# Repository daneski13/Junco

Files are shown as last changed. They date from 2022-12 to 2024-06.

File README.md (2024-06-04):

<h1 align="center">Junco</h1>






Named after a small North American bird, Junco is a 60% Raspberry Pi Pico powered split keyboard boasting a 4x6 layout with an aggressive columnar stagger, 2-4 rotary encoders, and per-key RGB lighting.

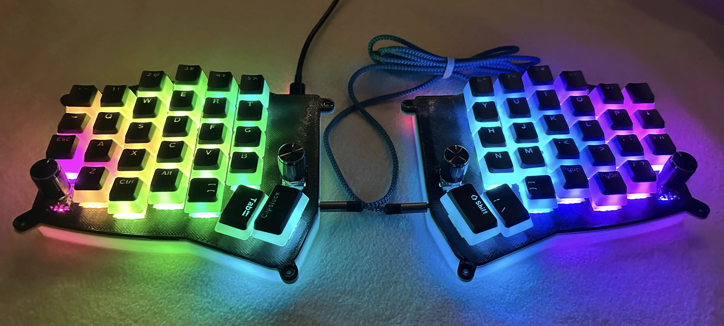
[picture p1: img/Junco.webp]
Junco


Want to contribute? Check out [Contributing](./CONTRIBUTING.md).

Junco is inspired by the excellent [crkbd](https://github.com/foostan/crkbd), [Iris](https://keeb.io/collections/iris-split-ergonomic-keyboard/products/iris-keyboard-split-ergonomic-keyboard), [Kimiko](https://github.com/Keycapsss/Kimiko), [Sofle](https://github.com/josefadamcik/SofleKeyboard), and [Ferris](https://github.com/pierrechevalier83/ferris) keyboards. Massive thanks to [@JellyTitan](https://github.com/JellyTitan) for the wiring overhaul.

- [Design Philosophy and Quirks](#design-philosophy-and-quirks)
  - [Philosophy](#philosophy)
  - [Quirks](#quirks)
- [Build Guide / Assembly](#build-guide--assembly)
  - [Parts](#parts)
    - [Required](#required)
    - [Optional - RGB](#optional---rgb)
  - [Soldering](#soldering)
    - [Diodes](#diodes)
    - [RGB (Optional)](#rgb-optional)
    - [Pico](#pico)
    - [Hot-swap Sockets](#hot-swap-sockets)
    - [TRRS jack and Rotary Encoders](#trrs-jack-and-rotary-encoders)
  - [Case](#case)
  - [Flashing the firmware](#flashing-the-firmware)
- [Troubleshooting](#troubleshooting)
  - [No LEDs are working](#no-leds-are-working)
  - [Some LEDs are not working](#some-leds-are-not-working)
  - [An entire row or column of keys is not working](#an-entire-row-or-column-of-keys-is-not-working)
  - [Random key or keys not working](#random-key-or-keys-not-working)

## Design Philosophy and Quirks

### Philosophy

In my search for an ergonomic split keyboard, I came across several great keyboards, but I craved a combination of features and ideas from several with my own flavor. Iris' aesthetics, Kimiko's stagger and layout, elements of Ferris' philosophy.

I also wanted to use Raspberry Pi Picos for the controller as it has many advantages over the ProMicro that is normally used in custom keyboards. At the time, Pico powered keyboards were not yet really a thing and weren't yet supported by the main QMK branch. Thus, I created my own keyboard.

The Junco was designed around a set of goals, similar in vain to the Ferris.

**Goals:**

- Low-Cost
- Raspberry Pi Pico / RP2040
  - Superior flash storage and processing power compared to the common ATMega32 ProMicro
  - Faster than STM32 blackpill with more flash storage at the same cost or less
- Comfort
  - Aggressive Columnar Stagger
- Aesthetics
  - Almost all soldering done on the backside of PCB, optional RGB
- 60% layout
  - Near perfect blend of compactness and easy use without crazy combos or layer gymnastics
- Multiple rotary encoder support
- Hot-swap switches
- Plug and play either side of the split
  - Convenience and traveling
  - Flexible cable management
- Minimal different parts and easy to source
  - No need to buy a different types of LEDs or diodes. No reset switches, capacitors, resistors etc. required.

**Non-goals:**

- Reversible PCB
  - Can make assembly confusing and more error prone
- Multi-switch support
  - MX switches should use MX spacing, Choc switches should use Choc spacing.
- OLED Support
  - OLEDs are an added cost and somewhat comprise the aesthetics in my opinion. Don't find useful for a keyboard, more of a novelty.

### Quirks

Being my first venture into keyboard design... Junco unfortunately suffers from a few "quirks" at the moment that may or may not bother you:

- The case files currently provided in this repo assume PCB mounted switches and uses a 3mm switch plate that is flush with the PCB. This presents some problems that a more proper suspended switch plate would not have:
  - Mounting the Pico on the backside with headers causes a bit of the header to be exposed on the front side of the PCB, so the switch plate provided in this repo will not sit flush with the PCB.
  - The TRRS jack is also soldered on the backside, causing another uneven surface for the switch plate.
  - Thus, material must be removed from the back of the switch plate in the proper places for a flush fit.
    - Heat-gunning the switch plate in the proper area, lining it up with the PCB, and squishing provides a quick and *dirty* solution if done correctly.
  - **PRs are welcome to improve upon the case files or to create new cases as I am a 3D design novice.** A proper fix would be to have the PCB rest on the middle section's lip about 1.5mm below the switch plate. This would also allow plate mounted switches to properly latch onto the switch plate.

## Build Guide / Assembly

### Parts

#### Required

Where "56-58" is the count, 58 is needed with 2 rotary encoders. subtract from 58 every additional encoder (4 encoders 56, with 3 encoders 57).

| Name | Count | Remarks | Potential Storefront |
| --- | --- | --- | --- |
| PCB | 2 (1 left and 1 right)  | PCBs can be ordered from manufacturers such as JLCPCB and LCSC | |
| MX Hot-swap Sockets | 56-58 | | |
| Diodes | 62 | Surface mount SOD-123 1N4148, _or_ through-hole 1N4148 diode. These are both common and inexpensive, any one should do. Through hole is usually easier to solder. | SMD: [AliExpress](https://www.aliexpress.us/item/2251832663565152.html) <br>[JLCPCB Part#: C2972760](https://jlcpcb.com/partdetail/3368026-1N4148SOD123/C2972760)<br> Through-hole: [AliExpress](https://www.aliexpress.us/item/2251832473773777.html) |
| Raspberry Pi Picos | 2 | PCB is specifically designed with the official Pico and YD-2040 type clone in mind, however several [other clone types](https://docs.google.com/spreadsheets/d/1LPjy6F5lHfUkmsrM5zlZmc5auYy5YBakW8Awe6hYFWo) should be compatible (Waveshare, WeAct, EstarDyn, Tenstar). Also, the case is currently designed assuming the Pico is soldered with [headers](https://www.sparkfun.com/products/17907), but surface mounting the Pico is supported on the PCB. | [AliExpress, YD-2040](https://www.aliexpress.us/item/3256803909832318.html) |
| TRRS Jacks | 2 | PJ-320A | [AliExpress](https://www.aliexpress.us/item/2255800474897706.html) |
| TRRS Cable (3.5mm "Headphone" Cable) | 1 | TRRS (4 pole) is currently required, not TRS (3 pole) | |
| MX Style Switches | 56-58 | | |
| Key Caps | 56-58 | | |
| Rotary Encoders and Caps | 2-4 | EC-11 Rotary Encoder | [AliExpress](https://www.aliexpress.us/item/2261799870168498.html) |
| M3 6mm or 6mm+ Screws and Nuts | 8 | | |
| Case | 1 Left Set, 1 Right Set | Case files are located in the [case folder](./Case). | |
| Micro USB Cable or USB-C Cable | 1 | USB cable for connecting the keyboard to your computer, dependent on what the Pico you chose uses. | |

#### Optional - RGB

These parts are necessary for the RGB lighting.

| Name | Count | Remarks | Potential Storefront |
| --- | ----- | --- | --- |
| 74AHCT1G125 Voltage Level Shifter/ Bus Buffer | 2 | SOT23-5 Footprint <br/> <br/> Required for LEDs to work properly, Pico runs at 3.3V while the LEDs will require 5V | [AliExpress](https://www.aliexpress.us/item/3256803831434811.html) <br> [JLCPCB Part# C7484](https://jlcpcb.com/partdetail/TexasInstruments-SN74AHCT1G125DBVR/C7484) |
| RGB SMD LEDs (Prefer SK6803MINI-E) | 74 | The 3MA SK6803MINI-E is highly recommended over the more traditional 12MA SK6812MINI-E due to its smaller current draw, allowing the LEDs to be very bright at manageable wattage. | [AliExpress](https://www.aliexpress.us/item/3256803450292556.html) <br> [JLCPCB Part# C5184589](https://jlcpcb.com/partdetail/Normand-SK6803MINIE/C5184589) |

### Soldering

The PCB is not reversible, there is a dedicated right and left half in the KiCad PCB files. Almost all of the soldering will occur on the backside of the PCB. 

#### Diodes

Solder the diodes as you see in the photo.
SMD diodes are soldered on the back of the board. 
Through-hole diodes are inserted on the back of the board, and soldered on the front.

> [!WARNING]
> **Note** that the diodes have polarity, ensure the line on the diode matches the silkscreen.

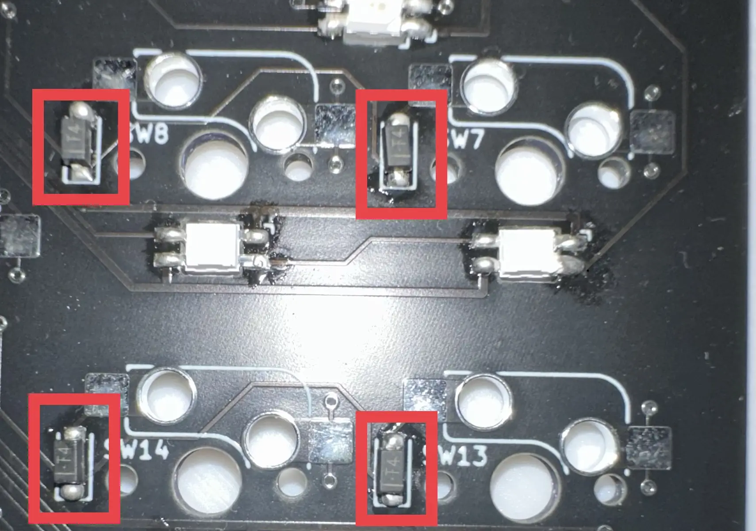
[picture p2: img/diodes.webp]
Soldered Diodes

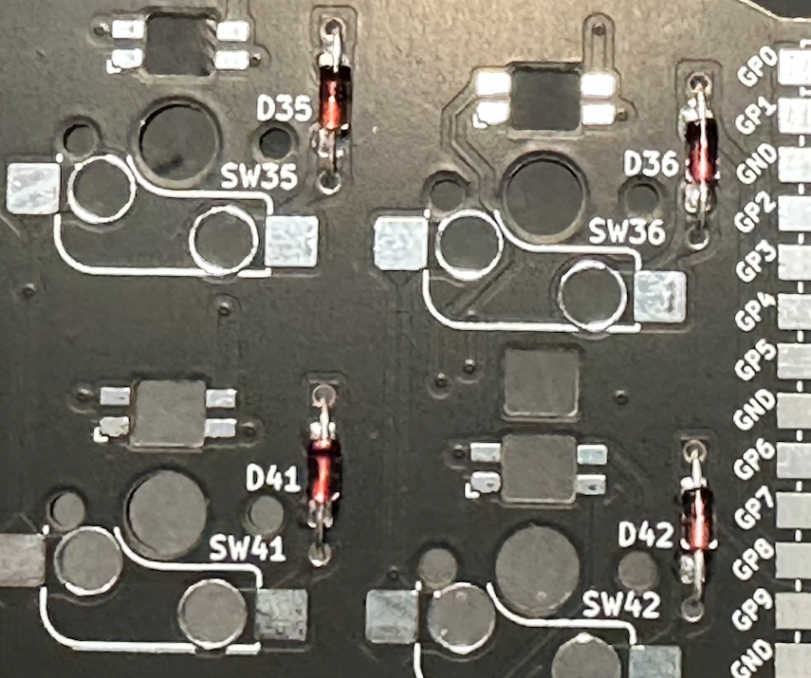
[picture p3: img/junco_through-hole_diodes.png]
Soldered Diodes

#### RGB (Optional)

All LEDs must be soldered to the PCB for RGB to work properly, even if you will not be using backlight or will be using an encoder that covers an LED. (They are wired in serial).

First solder the level shifter. It's tiny & squirrley - [drag soldering](https://www.youtube.com/watch?v=wUyetZ5RtPs)" is a good method. See photo:

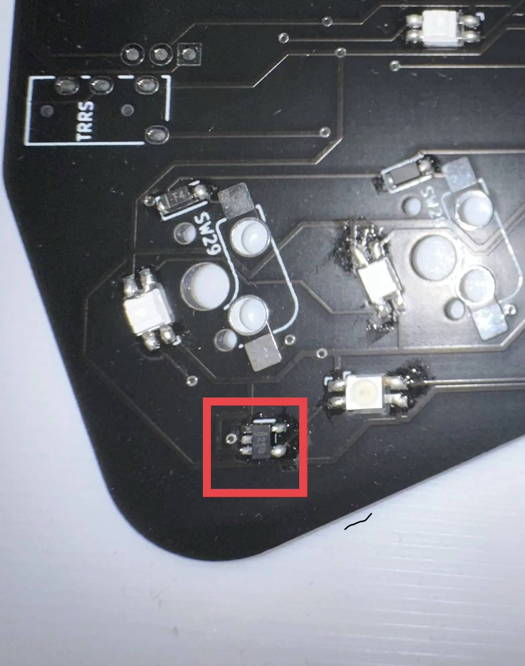
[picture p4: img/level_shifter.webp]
Level Shifter Soldered


All LEDs will be soldered facing _down into the board_. The LEDS for per-key RGB will be soldered on the back of the board, while the LED's for the underglow will be soldered on the front of the board.

> [!WARNING]
> **Note** the LED orientation is very important. One of the pads on each LED (the ground pin) will be misshapen relative to the others, this pad should connect to the PCB pad that is marked by the L shape on the silkscreen. For a sanity check, a corner of the LED's front-side will also be "cut", this corner must also line up with the L shape on the silkscreen.

 Blue is LEDs that will be installed on the underside of the board, facing the front-side of the PCB for the per-key lighting. Red will be installed on the front of the board for the underglow:

LED Orientation

Per Key leds soldered on the backside, while underglow LEDs ssoldered on the opposite side:
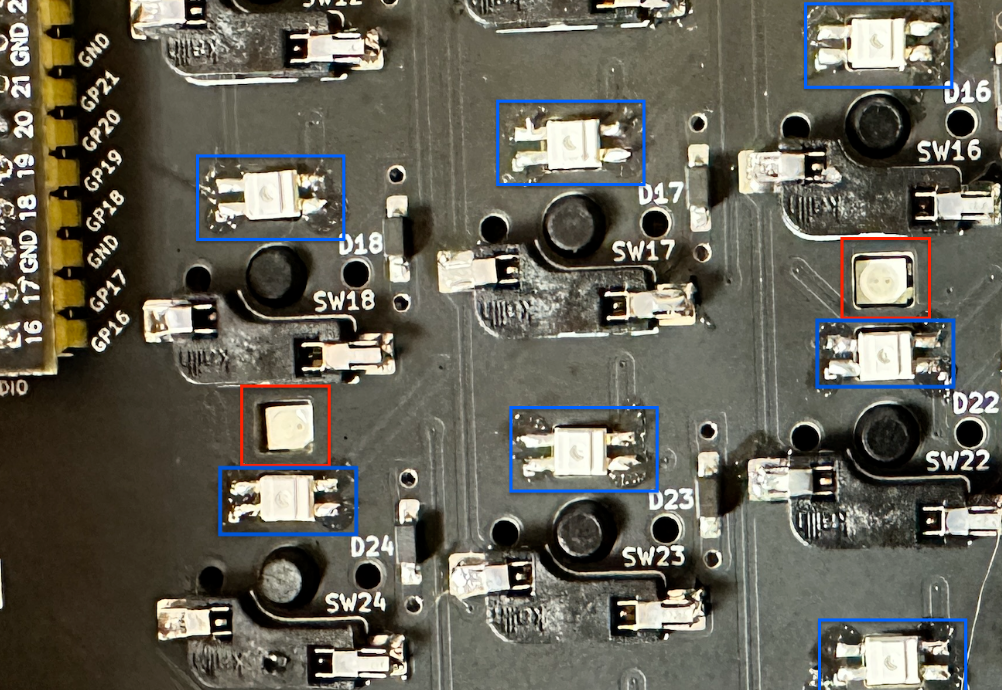
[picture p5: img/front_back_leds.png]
LEDs Soldered


Ground pin orientation:

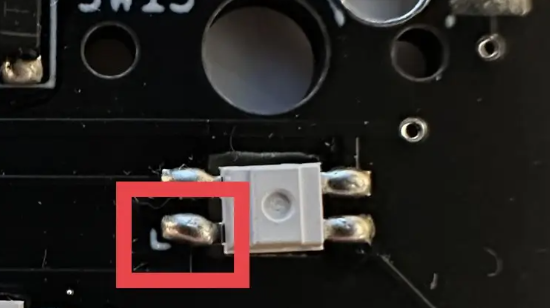
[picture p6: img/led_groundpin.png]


After you finish the next step of soldering the Pico to the PCB, recommend plugging the keyboard in and flashing QMK to ensure the LEDs are lighting up. If there are any issues, check the troubleshooting section.

#### Pico

If you are soldering the Pico surface mount style, go ahead with soldering it to the backside of the PCB and you can skip to the next section.

If you are soldering the Pico using headers, first solder the Pico to the headers and then the header/Pico to the PCB. 

**Ensure that you are soldering the Pico/Header onto the backside of the PCB.**

The best way to go about this method is to rest the shorter end of the headers in the through-holes of the PCB on a flat surface and place the Pico on top, through the longer end of the header. This will stabilize the headers somewhat and ensure proper spacing. Solder the Pico to the 2 header pins on the both the "top" and "bottom" of the Pico to hold it in place. Proceed to solder the Pico to the rest of the header's pins.

After the Pico is soldered to the header, flip the PCB over and solder the sticking-out header pins to the PCB. Start with the 2 "top" and 2 "bottom" header pins to hold it in place, being sure to minimize the space between the header's plastic and the PCB. Proceed to solder the PCB to the rest of the header's pins.

The end result will look like this:

Backside of PCB:

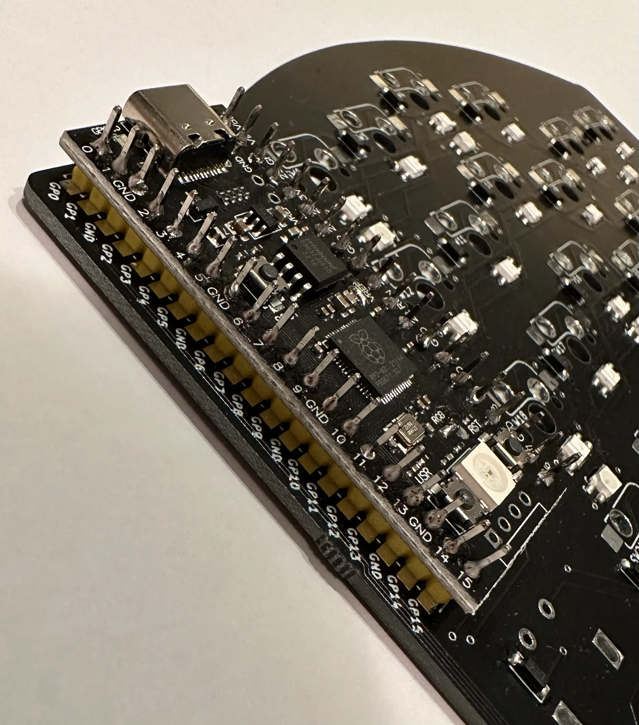
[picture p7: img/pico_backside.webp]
Pico Soldered, PCB Backside


Front-side of PCB:

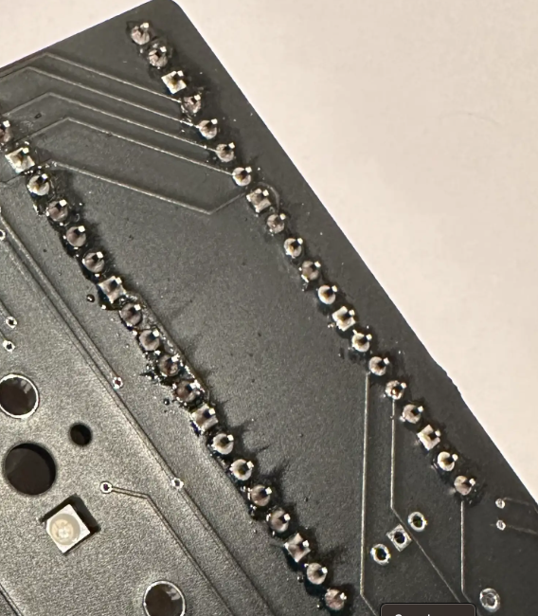
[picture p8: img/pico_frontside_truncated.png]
Pico Soldered, PCB Frontside


#### Hot-swap Sockets

Place hot-swap sockets on the backside of the PCB and solder. See photo:

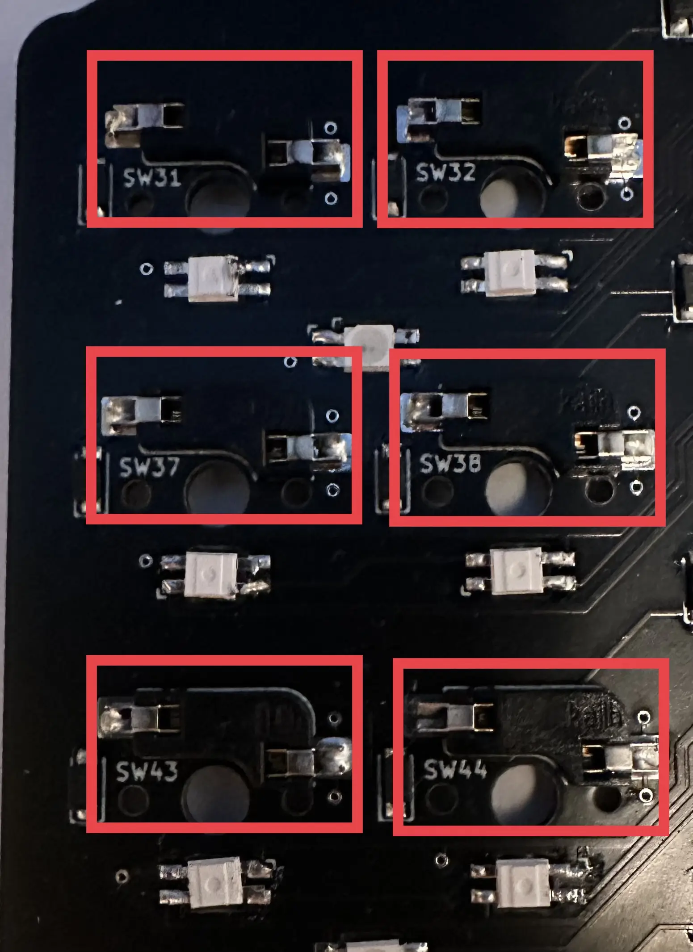
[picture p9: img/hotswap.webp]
Hot-swap Sockets Soldered


#### TRRS jack and Rotary Encoders

The process for soldering the TRRS jack and the process for the rotary encoders are very similar.

On the **backside** of the PCB, place the TRRS jack. On the front-side of the PCB, bend the pins of the TRRS jack to "latch" onto the PCB and solder.

Backside PCB:

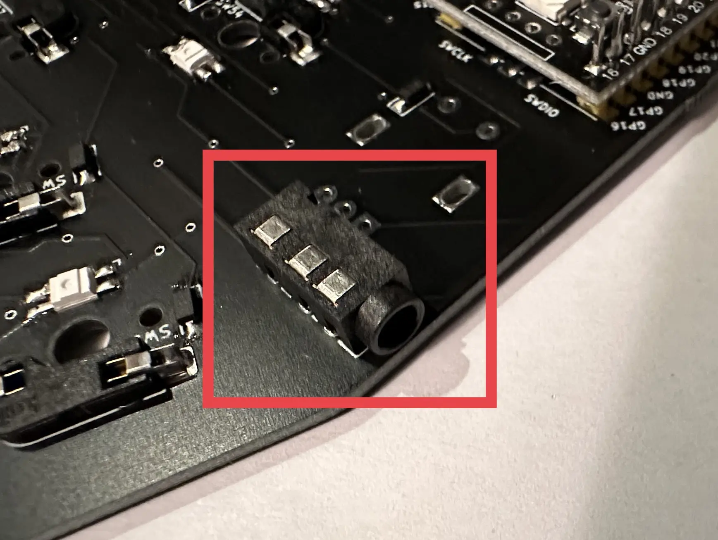
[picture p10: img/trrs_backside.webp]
TRRS Soldered, Backside


Front-side PCB:

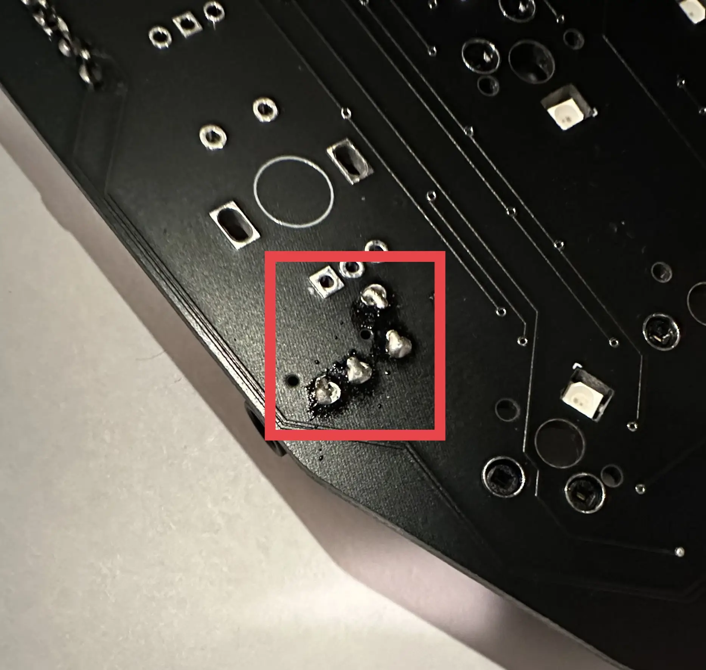
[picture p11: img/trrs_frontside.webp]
TRRS Soldered, Front-side


On the **front-side** of the PCB, place the rotary encoder(s). On the backside of the PCB, bend the pins of the encoder to "latch" onto the PCB and solder.

Front-side PCB:

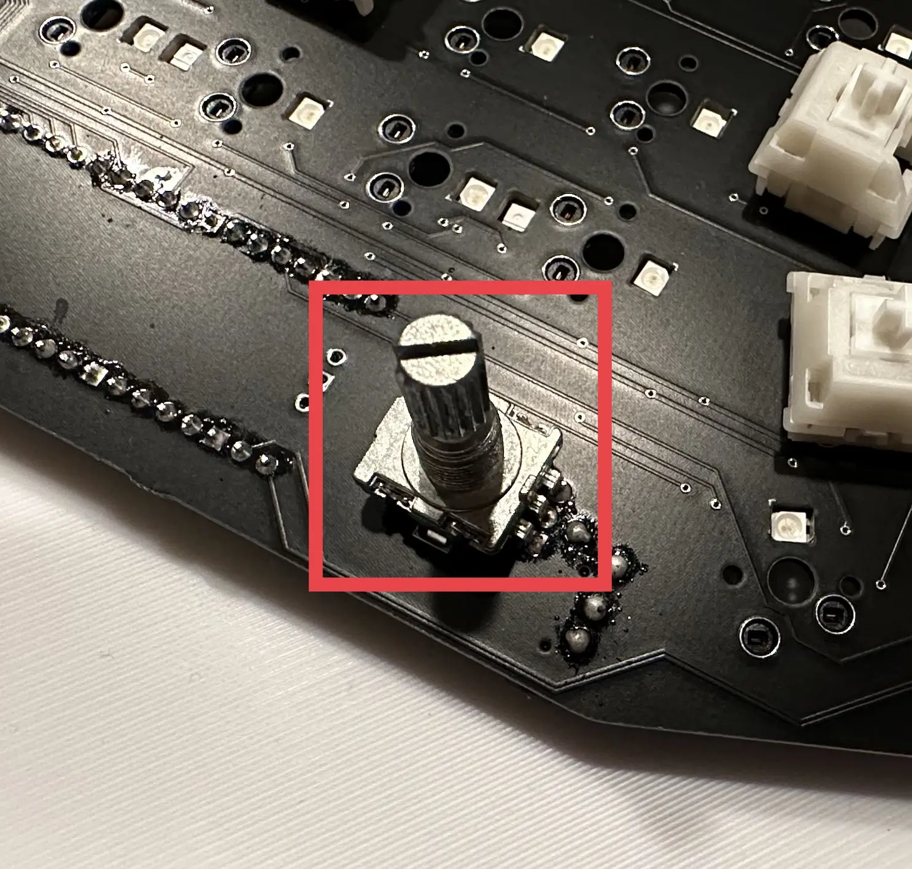
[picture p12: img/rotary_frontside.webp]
Rotary Encoder Soldered, Front-side


Backside PCB:

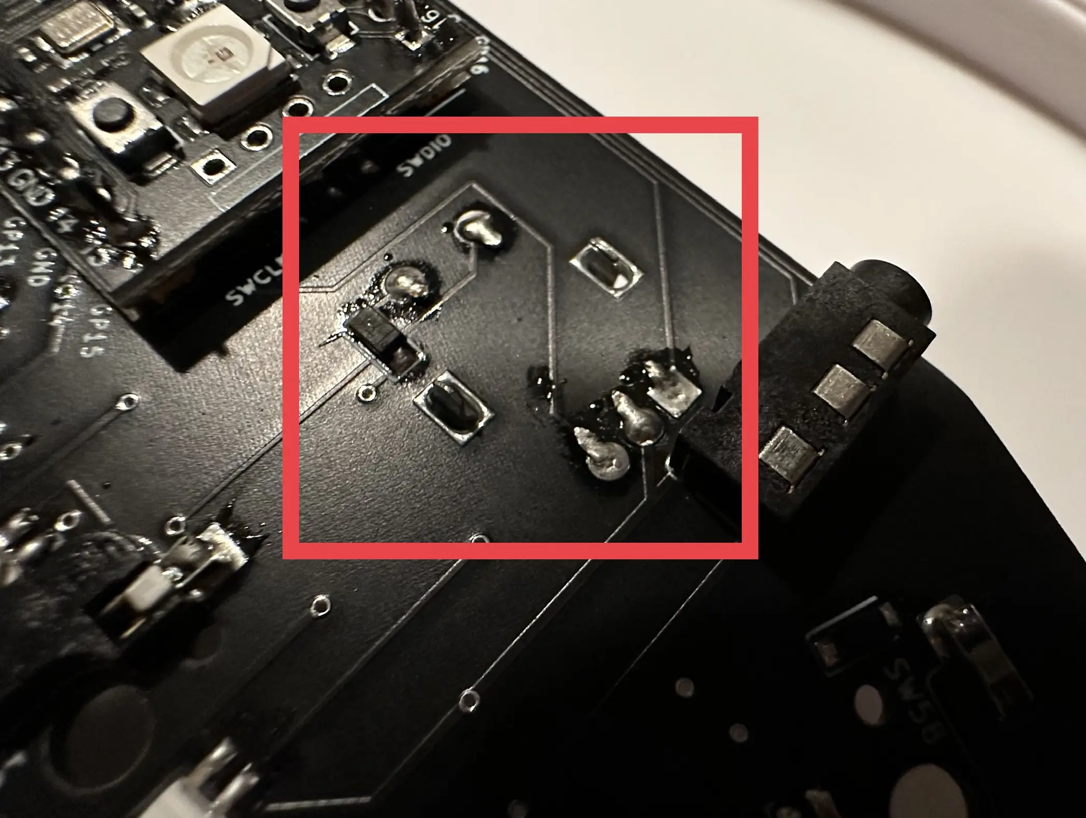
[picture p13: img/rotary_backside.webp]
Rotary Encoder Soldered, Back-side


### Case

At the moment, the case files included in the [case directory](./Case) support 3D printing of a case assuming PCB mounted switches (since the 3mm switch plate is resting on the PCB). Since I do not own or have easy access to a 3D printer, the case was designed to be easy to print with 3rd party printing services in-mind such as Treatstock.

Raw files are provided for designing your own case if you see fit. Further work on the case may occur in the future to properly suspend the switch plate. PRs are welcome.

The case is comprised of 4 parts, 8 M3 screws, and 8 M3 nuts.

To have a functional case you need the Bottom Left and Bottom Right along with a Left Switch Plate and a Right Switch Plate. 4 M3 screws and their nuts will hold the switch plate and bottom together for each side of the split. Recommend printing the bottom in white at 40% infill so the underglow LEDs can bleed through.

The naming schemes "- 2 Rotary" and "- 4 Rotary" are products of the raw files used to model the case.

The switch plates named "- 2 Rotary" assume 1 rotary encoder will be used on that side of the split. One by they thumb keys.

The switch plates named "- 4 Rotary" assume 2 rotary encoders will be used on that side of the split. One by the thumb keys and one in the far bottom corner

If you would like to have 3 rotary encoders rather than 2 total or 4 total you would use both variants. The side that will have 2 rotary encoders will use the "- 4 Rotary", while the other side with 1 rotary encoder will use the "- 2 Rotary".

As mentioned in [design quirks](#quirks), there are some problems with making the switch plate flush with the PCB. After you get it flush, you can completely assemble your keyboard! Assembly goes in the reverse of the following:

-- Keycaps --

-- Switches --

-- Case Switch Plate -- (screw + nut connect the plate with the bottom)

-- PCB --

-- Case Bottom --

### Flashing the firmware

Junco is powered by the QMK firmware, see the [build environment setup](https://docs.qmk.fm/#/getting_started_build_tools). Brand new to QMK? Start with the [Complete Newbs Guide](https://docs.qmk.fm/#/newbs).

For users wanting something a little more fun, check out my keymap folder [here](./qmk) and my keymap [here](./qmk/keymaps/deluxe).

Flashing instructions can be found [here](https://github.com/qmk/qmk_firmware/tree/master/keyboards/junco).

Congratulations and enjoy your split keyboard!

## Troubleshooting

### No LEDs are working

Try the following until problem solved:

1. Ensure the level shifter is properly soldered onto the PCB, re-solder as needed.
2. There is a diode without a corresponding switch located to the top right of the Pico on both sides of the split, check and re-solder that diode as needed.
    1. Short the pads on either side of the diode on both halves.
       1. If some the LEDs turn on, re-solder the diodes. Replace it if problem persists.
       2. If no LEDs turn on after shorting the diode's pads, there is likely a problem with the first LED, move to the next section for the first LED in the electrical order. If that still doesn't work, the level shifter is likely damaged and needs to be replaced.

### Some LEDs are not working

Go through the LED electrical order (pictured below) until you reach the problem LED. That LED **or** the one previous to it has a problem.

LED Electrical Order (1-8 are underglow):

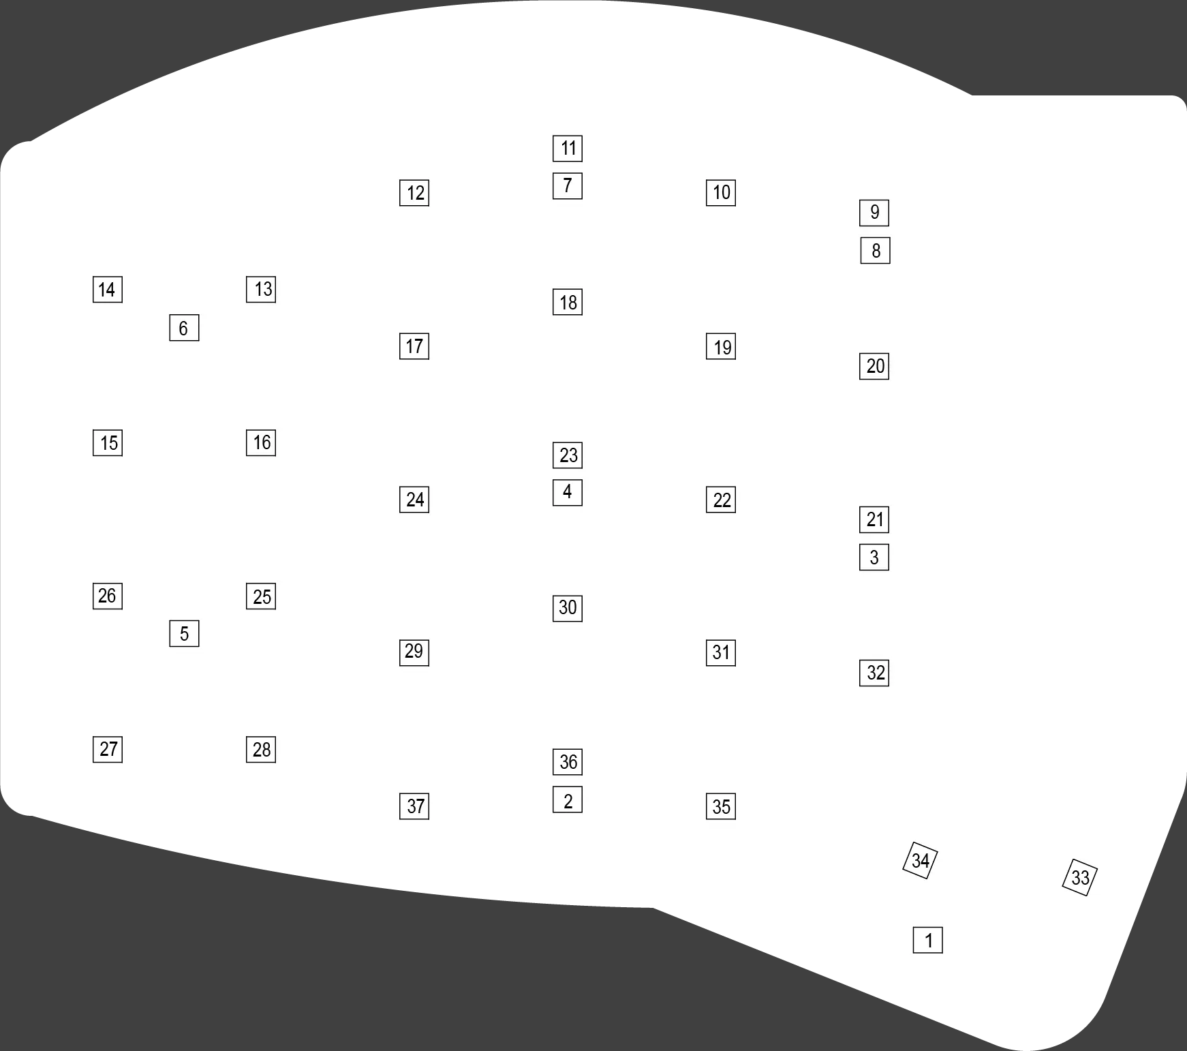
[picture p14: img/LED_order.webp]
LED Order


Right side is identical but mirrored.

Try the following until problem solved:

1. Check that the pads of LED not turning on and its previous are soldered correctly, re-solder for a better connection as needed.
2. Double check that the LED not turning on is in the correct orientation.
3. If the soldering looks good and the orientation is correct, try re-soldering all the pads any way for good measure.
4. If re-soldering didn't work than the LED is likely dead or damaged in which case replace it.

### An entire row or column of keys is not working

In this case, there is most likely a problem with the PCB's connection to the Pico. Note that the bottom row of keys is staggered by 2, so the the corresponding matrix column is shifted.

Rows:

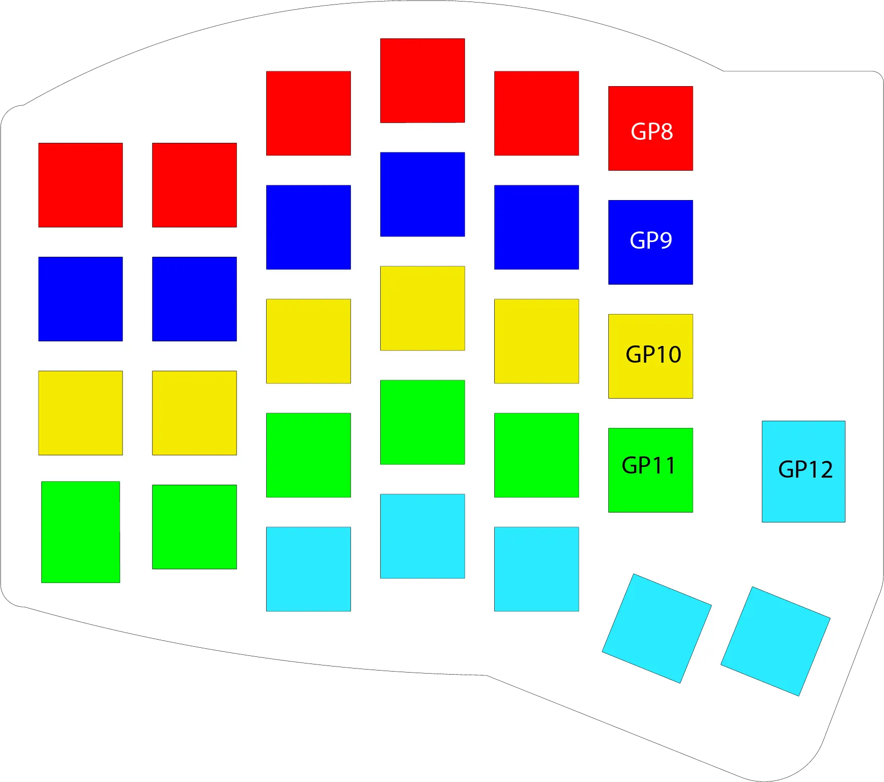
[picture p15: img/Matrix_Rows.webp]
Matrix Rows


Cols:

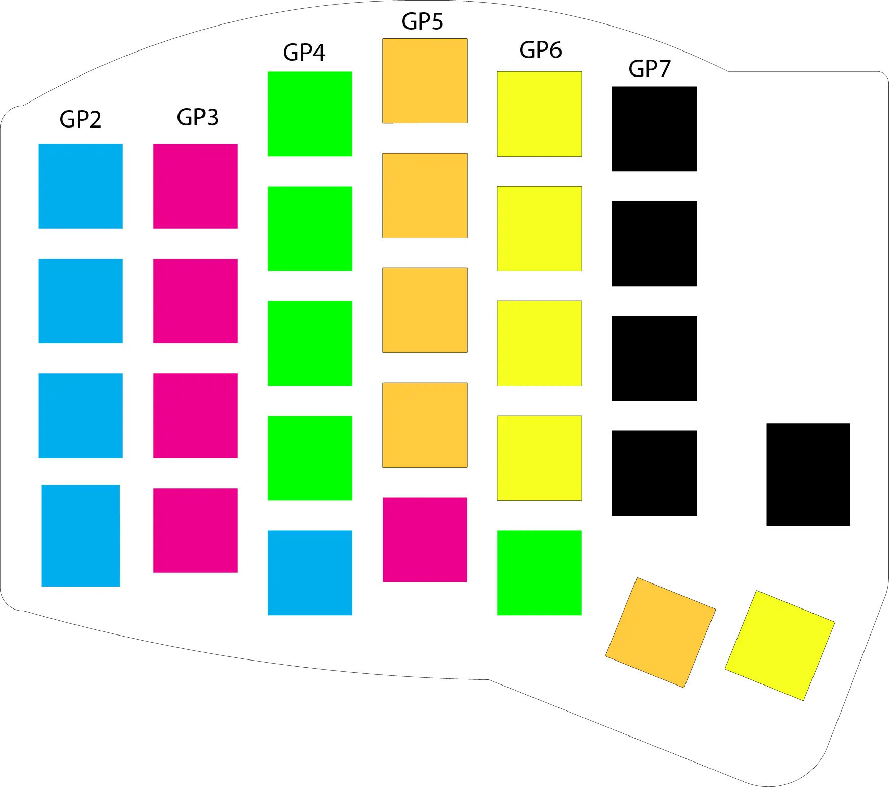
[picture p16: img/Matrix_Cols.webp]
Matrix Rows


The right side is identical but mirrored.

Try the following until problem solved:

1. Double check that you have soldered the Pico into the correct holes.
2. Ensure the soldering connections of the Pico to the PCB is good (if you used a header to solder the Pico onto the PCB one of the connections to the through-hole is likely bad). Re-solder as needed.
3. If none of the connections are obviously bad, use the image above to see what row/column corresponds to what connection (GP numbering on back of PCB). Re-solder that specific connection for good measure and test.
4. If re-soldering the connection didn't work, your Pico or PCB is likely damaged. Rule out the Pico by directly shorting the that row or column's corresponding pad on the Pico with another column/row pad (connecting one row and one column). If a key press is registered, there is a problem with your PCB, see the bottom of the next section about potentially fixing paths on the PCB. If no keypress is registered, the Pico is damaged and have fun de-soldering your Pico (hot-air station or careful work with a heat gun is the best way).

### Random key or keys not working

Note that the bottom row of keys is staggered by 2, so the the corresponding matrix column is shifted. See the photo in the above section.

If it's not a row or column of keys, than there is a bad connection between your switch and PCB.

Try the following until problem solved:

1. Re-seat the switch in the hot-swap socket.
2. Try a different switch.
3. Check the soldering of the hot-swap socket to the PCB, re-solder as needed
4. Short the PCB pads on either side of the hot-swap socket, if that registers a keypress, the hot-swap socket is bad and needs to replaced.
5. Check the diode.
   1. Check the soldering of the diode to the PCB and re-solder as needed.
   2. Double check that the diode is oriented correctly.
   3. Make sure diode actually works and has a good connection.
      1. Read the diode with a multimeter, typically reads a little more than 0.6. Higher numbers usually means the solder connection is bad, de-solder and re-solder the diode. If not reading, diode is bad and needs to be replaced.
      2. No multimeter? Short either side of the diode and press the key. If that works either the diode's connection is bad and re-solder, or the diode is dead and needs to be replaced.
6. If none of the above worked, the problem is most likely with the paths inside the PCB.
   1. You can try the following: (credit to [crkbd](https://github.com/foostan/crkbd) guide)
      1. "Visually inspect the PCB. If it looks scratched or damaged anywhere along the path from ProMicro to diode to keyswitch, the path might be interrupted. If you find a spot that looks damaged, you can use some wire to bypass the section that is damaged (e.g. connecting the ProMicro directly to the first pad of the diode). If this fixes the key, then you can either opt to keep the wire permanently, or you can try to repair the path. The path can be repaired by carefully scraping off the paint from a section of the path that is okay on either side of the damaged part (use a small flat head screwdriver intended for electronics). Then clean carefully with alcohol and solder a new connection. Youtube might have some guides on how to do this."

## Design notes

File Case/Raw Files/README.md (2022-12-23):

# Raw Files

The DXF files contained in this directory are in millimeters and generated from the KiCad PCB. They should be your starting point for creating a case.

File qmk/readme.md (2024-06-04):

> [!NOTE] 
> This folder contains most of the original QMK firmware files for the keyboard, some features were rejected by the main QMK repository as they were too user-keymap specific, complex, and depend on some internal workings of QMK that are subject to change/break in the future. This is not even currently guaranteed to work with the latest QMK firmware, but at the very least is an interesting starting point for anyone looking to make complex features for their own keyboards.
> 
> As such, they are not included in the main QMK repository. If you want to use these features, you will have to use this repo's junco keyboard files. Particularly of note is the [Junco Sync Feature](#junco-sync-) and [deluxe keymap](./keymaps/deluxe/)

# Junco <!-- omit from toc -->

Junco

Junco is a 60% Raspberry Pi Pico powered split keyboard boasting a 4x6 layout with an aggressive columnar stagger. It has 5 "thumb" keys on either side, support for 2-4 rotary encoders, and per-key RGB lighting.

- Keyboard Maintainer: [Dane Skalski](https://github.com/Daneski13)
- Hardware Supported: Junco PCB, Raspberry Pi Pico
- Hardware Availability: [PCB, Case, Parts List](https://github.com/Daneski13/Junco)

Remember you have to flash both halves of the keyboard for it to work!

Make example for this keyboard (after setting up your build environment):

    make junco:default

Flashing example for this keyboard:

```bash
# For flashing the left half...
make junco:default:uf2-split-left
# or the qmk cli equivalent:
qmk flash -kb junco --keymap default -bl uf2-split-left

# For flashing the right half...
make junco:default:uf2-split-right
# or the qmk cli equivalent:
qmk flash -kb junco --keymap default -bl uf2-split-right
```

See the [build environment setup](https://docs.qmk.fm/#/getting_started_build_tools) and the [make instructions](https://docs.qmk.fm/#/getting_started_make_guide) for more information. Brand new to QMK? Start with our [Complete Newbs Guide](https://docs.qmk.fm/#/newbs).

## Bootloader <!-- omit from toc -->

Enter the bootloader in 3 ways:

- **Bootmagic reset** (works after you have flashed once): Hold down the top far corner key while plugging in the keyboard (`~` left half, `-` right half). This will also clear the EEPROM.
- **Physical reset button**: Hold the `BOOT` button on the Pico and press the `RST` button on the Pico, release the the `RST` button before the `BOOT` button.
- **Keycode in layout**: In the default layout, the `Bootloader` keycode is above home row pinky on the right side's adjust layer.

Once you enter the bootloader, the keyboard will show up as a USB device on your computer, you could drag and drop a firmware file to flash it, but I recommend using the flash commands for the respective side.

## Junco Sync <!-- omit from toc -->

Junco has a special feature called Junco Sync that will automatically save and sync certain data between the halves of the split. This means that no matter which side you plug in, whenever you change your default layer in a keymap with `DF(layer)`, change your RGB settings with `RGB_***` keycodes, or use one of the `MAGIC_***` keycodes, the data will be saved to EEPROM and synced to the other half of the keyboard. If you choose to plug the other half into a computer, your settings will be the same.

Also, if you ever clear the EEPROM with `EE_CLR` or reboot with `QK_RBT` on one half, the other half will automatically do the same.

To enable Junco Sync in your firmware, uncomment `#define JUNCO_SYNC_ENABLE` in your `config.h` so it looks like this:

```c
/*  - Junco Sync -
    Enables a special feature that will sync
    data between the halves of the split keyboard.
    So no matter which side you plug in, your
    default layer, RGB settings, and any changes made
    via the Magic keycodes will be the same.
*/
#define JUNCO_SYNC_ENABLE

// ... Rest of config.h ...
```

Junco Sync will do its thing by default, but you can disable it at any time without having to re-compile your firmware. `junco_sync_disable()` will disable syncing and `junco_sync_enable()` will re-enable syncing (these settings will sync and persist between sides). Clearing EEPROM will re-enable Junco Sync since it's enabled by default. `is_junco_sync_enabled()` will tell you whether or not Junco Sync is enabled.

### Junco Sync - Advanced <!-- omit from toc -->

- [Settings](#settings)
- [Syncing User Data](#syncing-user-data)
- [Manually Trigger a Sync](#manually-trigger-a-sync)
- [Extras](#extras)

#### Settings

There is a couple of settings for Junco Sync that you can define in your `config.h`. They are:

- The time between syncs. This is to prevent syncs from happening back to back and/or retries happening too quickly, reducing keyboard responsiveness. The default by not defining anything is 1 second, but you can change it by defining `JUNCO_SYNC_THROTTLE` in your `config.h`.
- The number of retries a sync will attempt before giving up. The default is 10, but you can change it by defining `JUNCO_SYNC_RETRIES` in your `config.h`.

```c
    #define JUNCO_SYNC_THROTTLE 1000 // Throttle to 1 second (already default)
    #define JUNCO_SYNC_RETRIES 10 // Allow up to 10 retries (already default)
```

Both of these settings have very sane defaults so there is not really a benefit to defining them. Syncs shouldn't decrease responsiveness at all during normal keyboard use since they are only triggered after pressing keys that have an effect on EEPROM, which shouldn't happen during normal typing or gaming.

If for some reason you're having issues with syncs not working, you can try increasing the number of retries, but you should probably check if your TRRS cable or TRRS jack soldering job is the problem.

#### Syncing User Data

You can sync your own "user level" data between the halves, see [QMK's documentation](https://docs.qmk.fm/#/feature_eeprom) on the subject. To enable syncing of user data between the halves, set `user_config_raw_ptr` to your config's `raw` value in the `keyboard_post_init_user` after reading the config from EEPROM. For example:

```c
void keyboard_post_init_user(void) {
    // Read your config from EEPROM
    user_config.raw = eeconfig_read_user();
    // Set the pointer to your config's raw value
    user_config_raw_ptr = &user_config.raw;

    /* ... do stuff ... */
}
```

To sync your user data between the halves you can do:

```c
// Update your config
user_config.my_setting = 123;
// Trigger sync
kb_needs_sync = true;
```

The sync will save your config to both side's EEPROM so you so don't have to call `eeconfig_update_user(user_config.raw)` yourself.

For more info, see the next section about manually triggering a sync.

#### Manually Trigger a Sync

You can trigger sync updates manually by setting a flag in your `keymap.c`. You would want to do this if you are updating the default layer, magic settings, RGB, or rebooting / clearing EEPROM within `process_record_user`.

With Junco Sync...

- Magic settigs (`keymap_config`) will only be synced if a `MAGIC_***` keycode is pressed and not overridden by the user.
- Default layer will only become persistent and sync if a `DF(layer)` keycode is pressed.
- RGB will only be synced if a `RGB_***` keycode is pressed and not overridden by the user.
- Synced reboot and clear eeprom only happens when `QK_RBT` or `EE_CLR` is pressed and not overridden by the user.
- Custom user data between the halves won't be synced automatically, it won't know whenuser data needs to be synced.

Triggering a sync is as simple as setting the respective flag to true. For example:

*Don't worry if your IDE complains about any values being undefined, they will be defined if you have `#defne JUNCO_SYNC_ENABLE` in your config.h and your firmware should still compile.*

```c
/* Trigger a sync */
// Syncs keymap_config ("Magic" settings), 
// keyboard level config, default layer, and
// user level config (if you have set user_config_raw_ptr)
kb_needs_sync = true;

// Trigger a RGB sync
kb_needs_rgb_sync = true;

// Trigger a reboot and optionally an EEPROM clear
// .reset needs to be true even when you want to
// just clear EEPROM
kb_needs_reset = {
    .reset = true, // True will trigger a reboot
    .eeprom = true // True will clear EEPROM before rebooting
};
```

Once you have set a flag, the keyboard will carry out the action on it's own and set the flag back to false when it's complete. No need to worry about clearing the flags yourself.

If for some reason your sync isn't working, try setting the flag on the key's release instead of press.

#### Extras

- You can directly call Junco Sync functions by including the `junco_sync.h` header file in your `keymap.c`.
  - Even after calling `junco_sync_disable()`, you can still manually sync data between the halves by calling Junco Sync functions directly within your `housekeeping_task_user`. `junco.c` can give you some ideas on how to do this.

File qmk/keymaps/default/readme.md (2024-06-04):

# Default Junco Keymap

This is the default layout for Junco. For the most part it's a normal QWERTY layout. The exceptions being the thumb keys, rotary encoders, and lack of caps lock (which is replaced by escape).

One of the biggest features of QMK is it brings layers into the mix which can give you access to even more keys. There are 4 layers: the default/base layer (QWERTY), a symbol layer, an extension layer, and an adjust layer.

Layers are very similar to Shift on a normal keyboard, where "a" becomes "A" when holding down shift. With a custom layer, you can have "j" become "4" for example and make an entire side of the keyboard become a number pad.

The [symbol layer](#symbol-layer) is accessed by holding down backspace, the [extension layer](#extension-layer) is accessed by holding down delete, and the [adjust layer](#adjust-layer) is accessed by holding down both delete and backspace.

## Default Base Layer (QWERTY)

Grey keys are rotary encoders (the ones on far left and far right are optional). Middle legend is pressing down the encoder, bottom left legend is counter-clockwise turn, and bottom right legend is clockwise turn of the encoder.

Those arrows for the bottom legends on the encoders are mouse scroll directions.

Red legends are the layer activated by holding down a key.

Junco's QWERTY Layout

## Symbol Layer

This layer is accessed by holding down backspace on the base layer, thus that key is blacked out.

On the symbol layer, the right side is a number pad, and the left side contains all the typical symbols (geared for programming).

Holding down delete within the symbol layer will take you to the adjust layer.

Junco's Symbol Layer

## Extension Layer

This layer's theme is navigation/extras, its accessed by holding down delete on the base layer, thus that key is blacked out.

On the extension layer, the right side is the function keys in a number-pad-esque layout with screen brightness up/down, and the left side has navigation keys and caps lock. Also, the rotary on the right side encoder becomes media controls.

Holding down backspace within the extension layer will take you to the adjust layer.

Junco's Extension Layer

## Adjust Layer

This layer's theme is adjusting the keyboard's settings, it's accessed by holding down both delete and backspace on the base layer.

On the adjust layer, the right side is the keyboard's settings: clear data, reboot, toggle debug mode, enter the bootloader, and change the base layer between QWERTY and [Colemak-DH](#colemak-dh). The left side adjusts the RGB lighting.

Junco's Adjust Layer

## Colemak-DH

This keymap offers Colemak-DH as an alternative base layer to QWERTY.

QWERTY is default when flashing your keyboard, but you can change it to Colemak-DH by selecting it's key on the adjust layer.

If you've never heard of it, Colemak is a keyboard layout that was designed to be a more ergonomic, modern, efficient, and comfortable replacement to QWERTY. Colemak was designed to place the most common letters in english on the home row along with many of the most common bigrams together (two letters typed in a row). Colemak-DH is a variant of Colemak that moves D and H to beneath the index fingers rather than the home row since most people find it easier and faster to reach the keys that way rather than the middle of the home row.

Junco's Colemak-DH Layout

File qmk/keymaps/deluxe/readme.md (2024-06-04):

# Deluxe Junco Keymap

This is my personal keymap for Junco at time of writing. It has [VIA](https://www.caniusevia.com/) and [Junco Sync](../../README.md#junco-sync) enabled and departs from the [default layout](../default/README.md) with the encoder mappings and some extra keycodes.

Also, this keymap implements the ability to sync VIA settings between the keyboard halves (key to trigger on the [adjust layer](#adjust-layer)). It did not make sense to add this feature at the keyboard level within Junco Sync as VIA is not fundamental like the default layer, RGB lighting, and Magic settings. VIA should be relegated to user keymaps.

This keymap also adds indicators when caps lock and num lock are enabled. When enabled, that key will become a static white (green on the white backlight mode) but only when the layer that respective key is on is active.

I wanted that classic rainbow barf RGB effect for the underglow even if the per-key lighting is something else, so I added 2 custom RGB matrix animations: white per-key lighting with rainbow underglow and pixel rain with rainbow underglow.

Here are some gifs of the animations:

White + Underglow Animation

Pixel Rain + Underglow Animation

## Base Layers

The base layers are the same as the default layout, except the right side's left encoder (by the thumb keys) is now media controls. Since I am using all 4 encoders it doesn't make sense to have 2 mouse scroll up/down, but for someone with just 2 encoders it may make sense to have media controls on a layer.

QWERTY:

QWERTY Layer

Colemak-DH:

Colemak-DH Layer

## Symbol Layer

Symbol layer is identical to the default layout.

Symbol Layer

## Extension Layer

Encoders on the right side become undo/redo and scrolling horizontally by word.

Extension Layer

## Adjust Layer

Pressing "Stick Adj Layer" will "stick" the adjust layer so you can use the rotary encoders for RGB settings rather than holding down both backspace and delete. To go back to the default layer, press that stick key again or press and release either Del or Backspace. When the adjust layer is currently "sticky" the sticky key will become the indicator color mentioned earlier.

"Toggle Base" will toggle between QWERTY and Colemak-DH, toggle OS will toggle between macOS and Windows key-mappings (swapping WIN/Command with Alt/Option by the thumb keys and properly mapping redo/word scrolling), "VIA Sync" will sync the VIA settings between the keyboard halves (there isn't a way to do this automatically), and "Toggle Junco Sync" will disable/enable Junco Sync.

Adjust layer

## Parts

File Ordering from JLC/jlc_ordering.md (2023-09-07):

# PCB Ordering Guide.
How to order this board from a PCB vendor - helpful info if it's your first time ordering a PCB, or if it's your first time using a PCB assembly service.

Most PCB vendors have a similar ordering process. I use [JLCPCB](https://jlcpcb.com/) because they are usually the most cost effective. I've had good luck with [Elecrow](https://www.elecrow.com/) too. [You can find PCB price comparison tools online.](https://pcbshopper.com/) When comparing pricing, the board dimensions for the Junco are 131mm x 297mm. (Usually anything under 100x100mm is really cheap - so be sure to use the 131x297 dimensions when pricing). PCB assembly is usually an extra fee, as well as the cost of components.

This guide covers ordering from JLCPCB using their PCB assembly service. Select components have been excluded from automated assembly to keep costs down.

## JLCPCB assembly service _is_ used for:
* Diodes. These cost about one cent USD each, so 5 boards sets with 315 diodes and 630 solder joints costs ~$3.55 USD.
* Level-shifter. There is no through hole variant available, and the smd can be difficult to hand solder.
* Per-key LEDs. These cost about the same to hand solder - but with 4 solder points per LED, thats' 232 joints per set, or 1160 solder joint per batch of 5 boards.
## Components JLCPCB assembly is _not_ used for:
* Pi Pico. These are not stocked at JLC. To be used in PCB assembly, you would need to have them shipped to and stored at JLC.
* Underglow LEDs. JLC charges for pcb assembly per-side. (Roughly $25 USD). We can't simply move these to the backside, because the orientation of the component in the tape reel determines which side faces up/down. Since these LEDs face the opposite direction of the per-key LED's, they must be installed on the opposite side of the board.
* Hotswop sockets. JLC considers these 'special' components, and charges an additional $25. (It's technically an upgrade from "Economic" to "Standard" assembly).

## Placing the order

Usually the minimum quantity to order is 5 boards. 

The production files are known as "gerbers", and they are usually uploaded as a `.zip` file. (It's essentially a collection of files for each layer of the board, like holes, graphics, traces etc.) 

In this repo, the zipped gerber file for the Junco can be found under [PCB/gerbers](https://github.com/daneski13/Junco/tree/main/PCB/gerbers/).
### Uploading the Gerber
The homepage of JLCPCB has a drag & drop upload. Drag the gerber `.zip` and drop it on the "add gerber file" box.
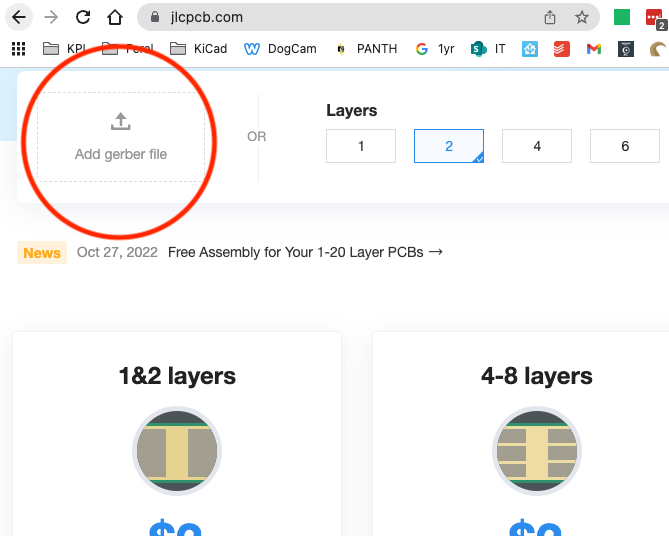
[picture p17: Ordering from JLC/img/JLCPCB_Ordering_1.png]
JLCPCB Home


### Basic options
While the file is uploading, it will take you to an options screen. Once the board size is detected<sup>1</sup>, the price<sup>3</sup> will update accordingly.
Changing the pcb color<sup>2</sup> may impact production time and price. If you use the PCB Assembly service, you will only be able to choose green or black, for no additional charge.
Shipping estimates<sup>4</sup> can vary widely, so be sure to check those. (You'll see these options again during checkout). It's not uncommon for shipping to exceed the cost of the boards.
The default pcb surface finish contains Lead. For boards in cases, this is usually not a problem. If you're going to rock a naked board, consider going with "lead free"<sup>5</sup> for a few bucks more. On the "Different design"<sup>6</sup> option, select "2". If you ignore this option, JLC will halt the order and charge you extra for having 2 designs on 1 pcb. 
I usually leave all the other options at the defaults.
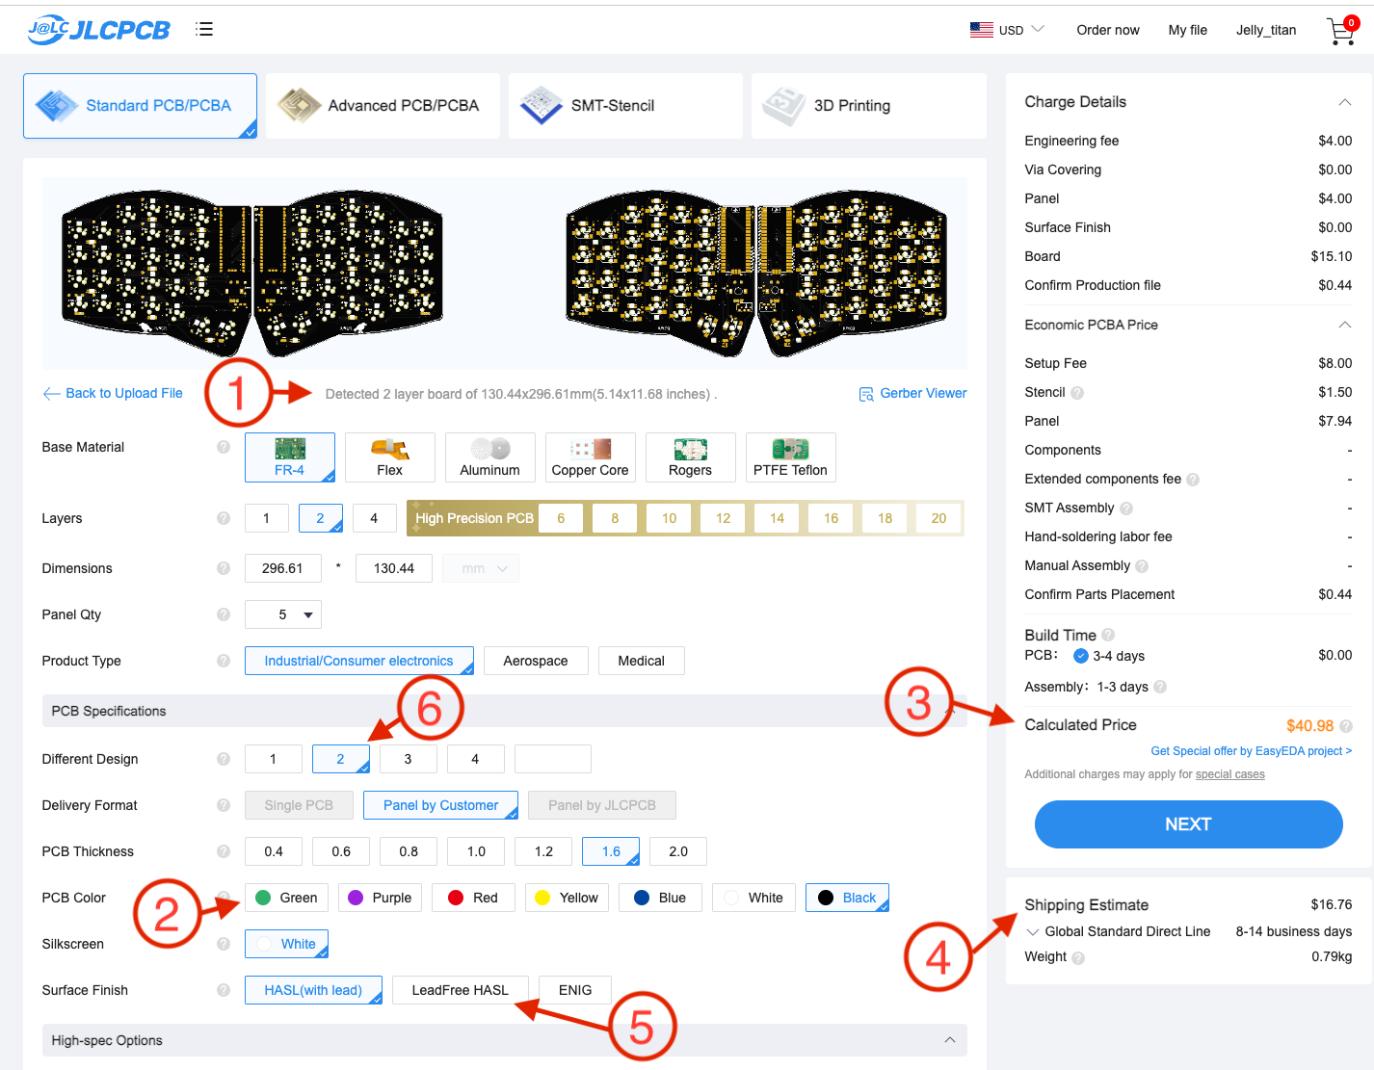
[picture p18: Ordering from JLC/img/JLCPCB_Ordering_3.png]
JLCPCB Home


### Order numbers
As part of the manufacturaing process, jlc will print an order number on the boards. If you select "specify a location", then jlc will use the location that has been designated in the gerber file, which is above the topmost middle finger. (Most people will never notice the order numbers regardless of the location).
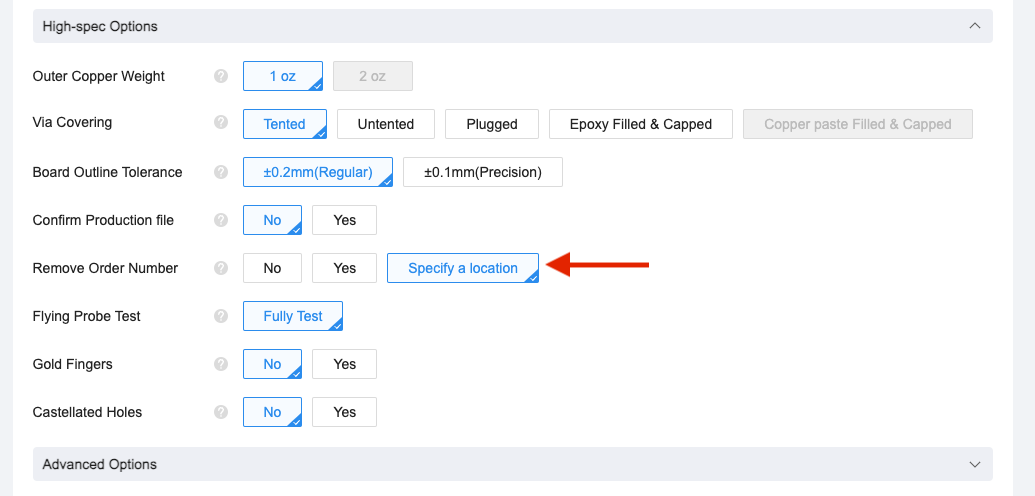
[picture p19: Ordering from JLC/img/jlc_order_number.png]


### PCB Assembly basic options
At the bottom of the page, there is a section for PCB assembly. Leave the PCBA Type on "Economic" and Select "Bottom side". You can also select either 2 or 5 PCBs to be assembled. (The rest of the screencaps are for assembly of 2 boards). I highly recommend the "Confirm Parts Placement" option. It costs a bit extra, but your assembly is reviewed by JLC before it goes into production. 
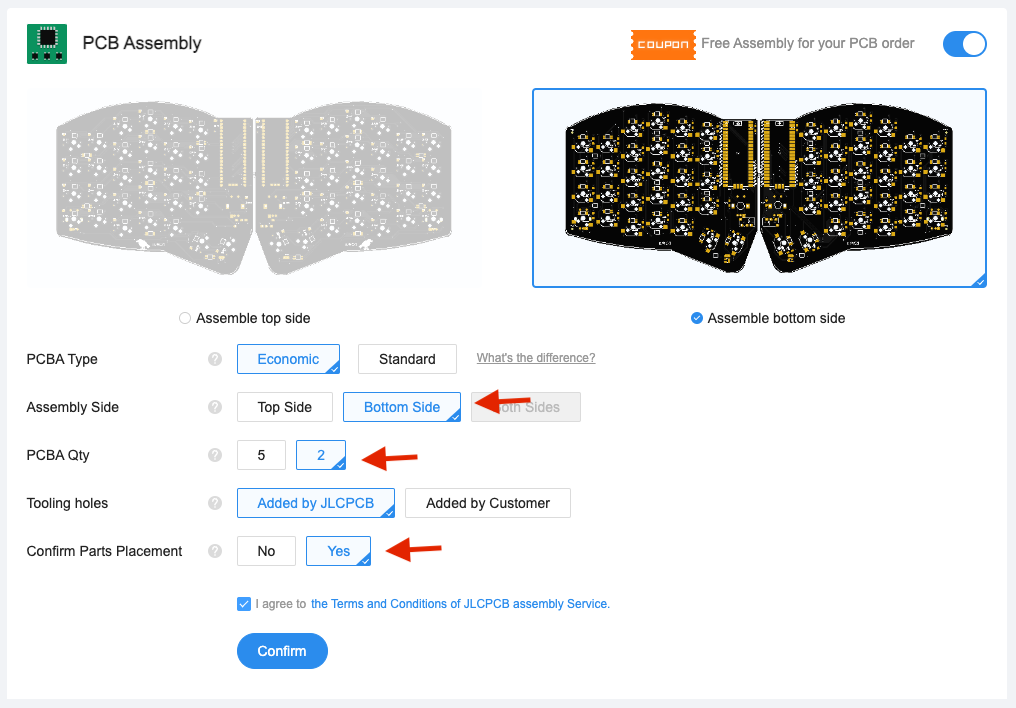
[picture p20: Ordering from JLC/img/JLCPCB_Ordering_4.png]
JLCPCB Home


### BOM & PNP Upload
After hitting "Next" on the PCB screen, you'll be taken to the "Bill of Materials" tab. It should show a render of the pcb:
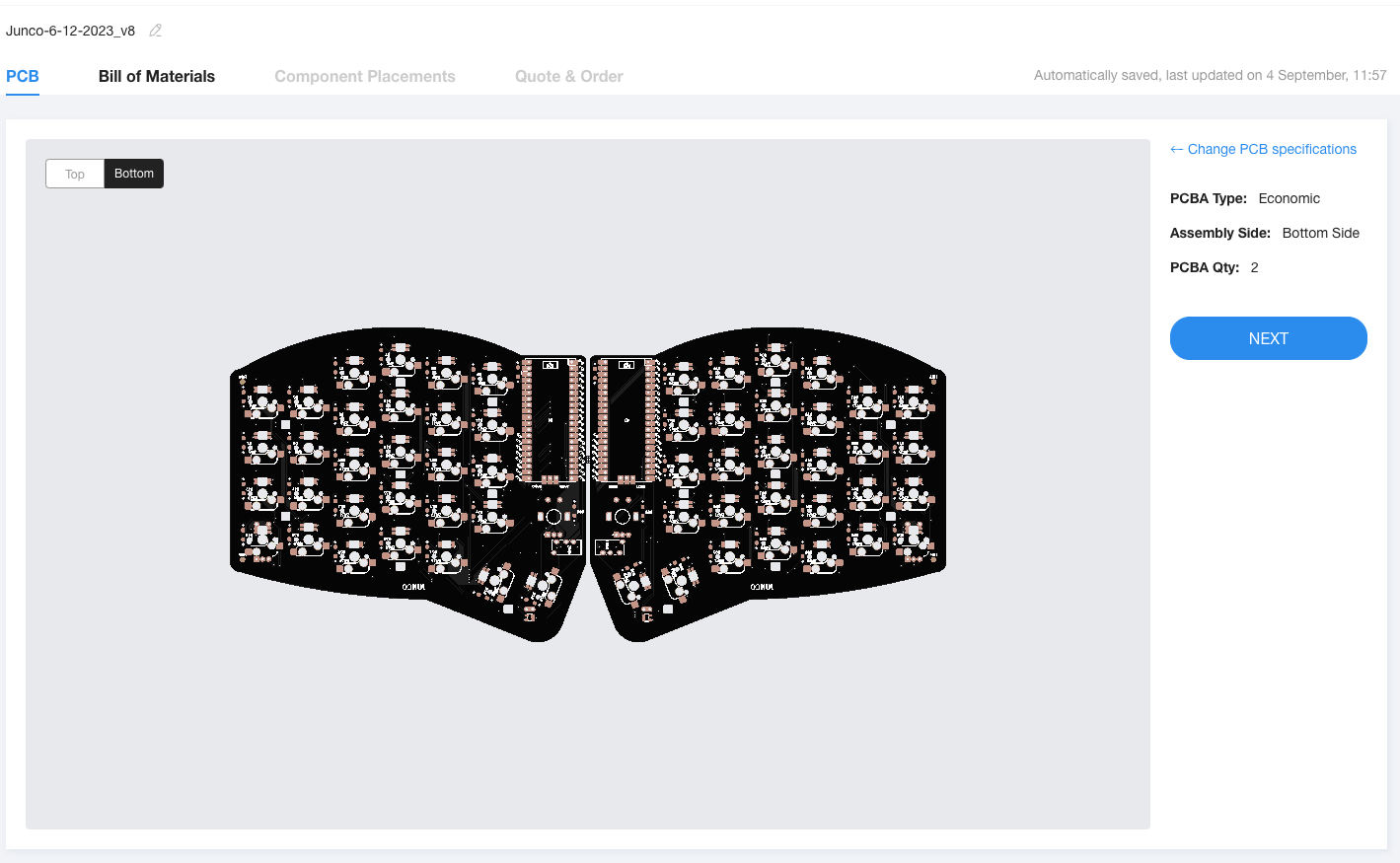
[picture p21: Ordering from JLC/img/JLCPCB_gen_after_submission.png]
JLCPCB Home

Clicking "Next" Will bring you to the BOM/PNP upload screen. Uplad the files in this folder titled `JUNCO v1.1 BOM JLC.csv` and `JUNCO v1.1 PNP Backside JLC.csv` These files are CSV's indicating the component type and locations.  These files were created by exporting them from KiCad, and then reformatting to meet JLCPCB specifications. These files are only intended for backside components. If you would like to use PCB Assembly services for front side components, you'll need to generate these files yourself.
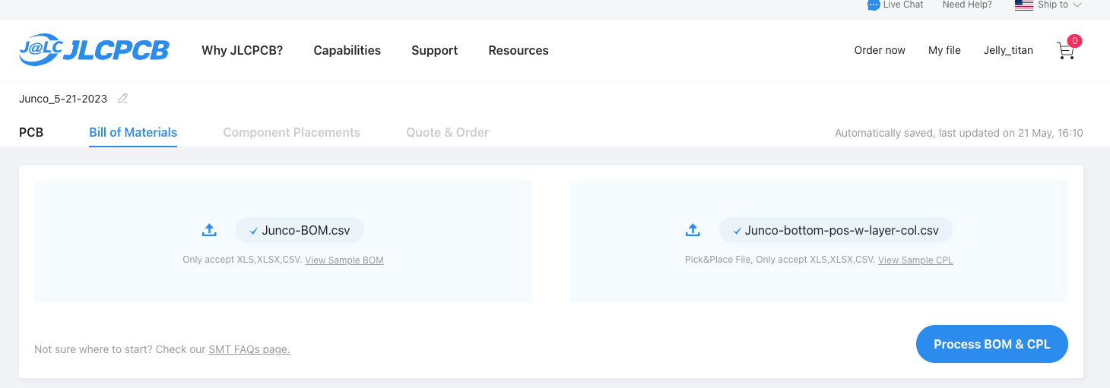
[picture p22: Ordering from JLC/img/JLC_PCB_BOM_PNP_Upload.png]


### Component confirmation
The next screen lets you select/deselect the components for assembly. 
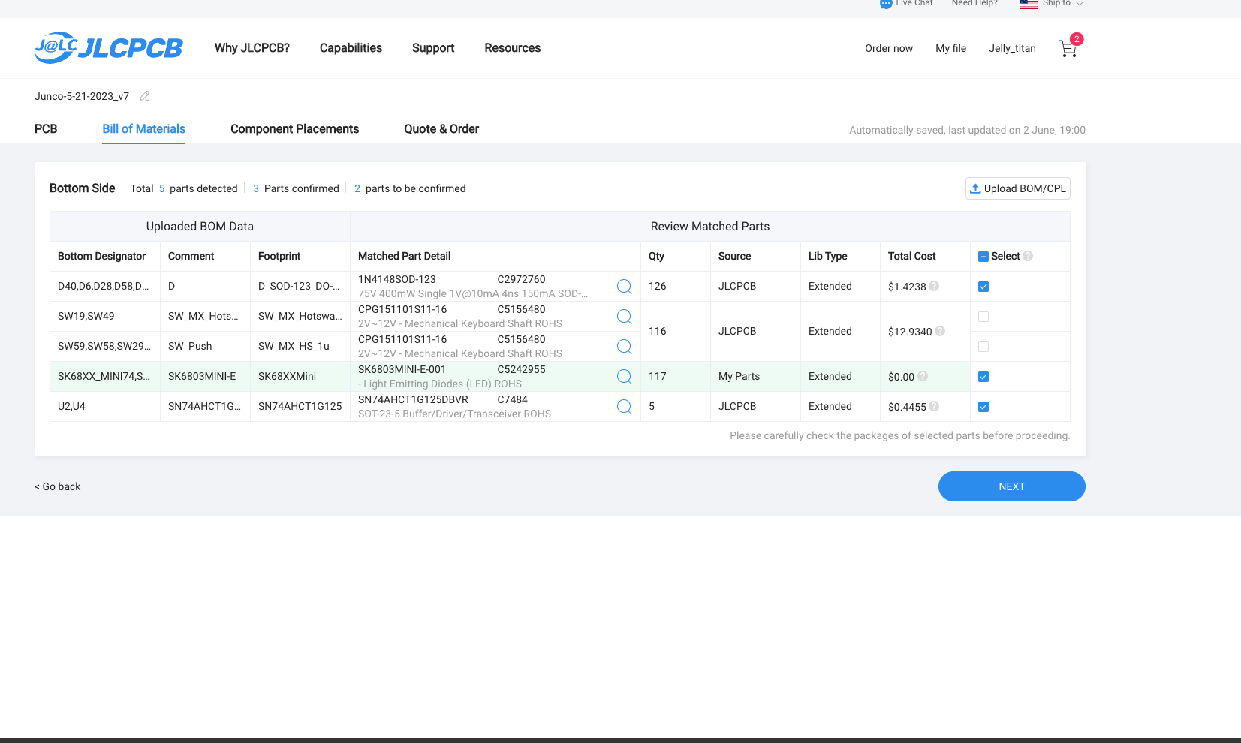
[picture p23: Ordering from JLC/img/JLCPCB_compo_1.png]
JLCPCB Home

If you select the hotswop sockets, you'll get an option to upgrade your assembly service, if you are willing to pay extra.
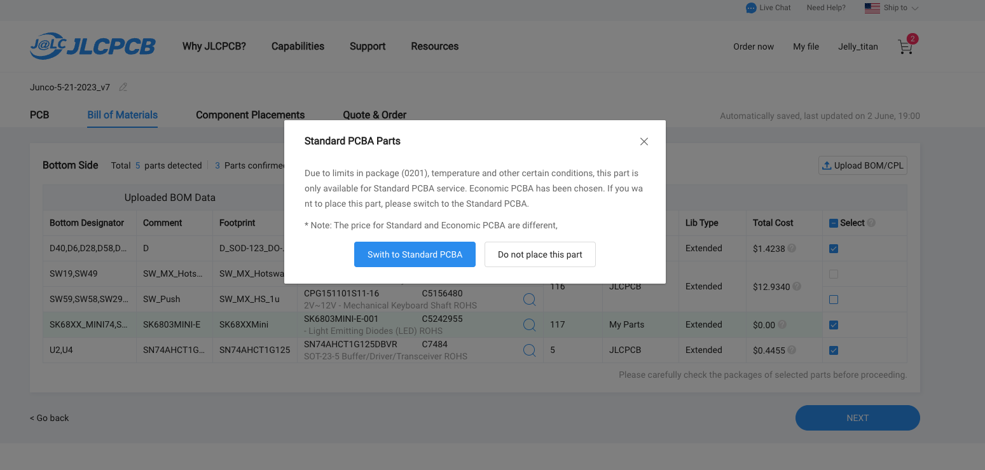
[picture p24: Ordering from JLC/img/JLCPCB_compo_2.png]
JLCPCB Home

Some components may be out of stock, like the SK61803 LED's in the screen caps. I had to order them separately, wait until they came in, and then place this order. (Which is why the cost is showing as 0). If you click "Next" while some parts are unselected, you will get this friendly warning error, which you can ignore if your deselection was intentional.
JLCPCB Home
After clicking "Next" you'll see a render depicting component placement. In my experience, this is always wrong, which is why i recommend the "Confirm Parts Placement" option. (I don't know if this is a JLC bug, or a board origin issue - but if you know - please submit a PR!)
JLCPCB Home
# Final Quote
The next tab is "Quote and order". 
JLCPCB Home

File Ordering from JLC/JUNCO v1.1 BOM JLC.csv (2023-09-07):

Comment | Designator | Footprint | JLCPCB Part #（optional）
SW_Push | SW59,SW58,SW29,SW28,SW24,SW50,SW20,SW32,SW3,SW51,SW37,SW17,SW38,SW31,SW52,SW56,SW27,SW40,SW6,SW46,SW25,SW43,SW14,SW13,SW4,SW16,SW5,SW36,SW21,SW55,SW48,SW18,SW45,SW54,SW39,SW47,SW12,SW26,SW34,SW23,SW10,SW15,SW35,SW57,SW8,SW22,SW44,SW42,SW9,SW41,SW53,SW33,SW11,SW1,SW7,SW2 | SW_MX_HS_1u | C5156480
SW_MX_Hotswap_Rotary_Switch | SW19,SW49 | SW_MX_Hotswap_Rotary_Switch | C5156480
SK6803MINI-E | SK68XX_Mini74,SK68XX_Mini73,SK68XX_Mini72,SK68XX_Mini71,SK68XX_Mini70,SK68XX_Mini69,SK68XX_Mini68,SK68XX_Mini67,SK68XX_Mini66,SK68XX_Mini65,SK68XX_Mini63,SK68XX_Mini62,SK68XX_Mini61,SK68XX_Mini60,SK68XX_Mini59,SK68XX_Mini58,SK68XX_Mini57,SK68XX_Mini56,SK68XX_Mini55,SK68XX_Mini54,SK68XX_Mini53,SK68XX_Mini52,SK68XX_Mini51,SK68XX_Mini50,SK68XX_Mini49,SK68XX_Mini48,SK68XX_Mini47,SK68XX_Mini46,SK68XX_Mini37,SK68XX_Mini36,SK68XX_Mini35,SK68XX_Mini34,SK68XX_Mini33,SK68XX_Mini32,SK68XX_Mini31,SK68XX_Mini30,SK68XX_Mini29,SK68XX_Mini28,SK68XX_Mini26,SK68XX_Mini25,SK68XX_Mini24,SK68XX_Mini23,SK68XX_Mini22,SK68XX_Mini21,SK68XX_Mini20,SK68XX_Mini19,SK68XX_Mini18,SK68XX_Mini17,SK68XX_Mini16,SK68XX_Mini15,SK68XX_Mini14,SK68XX_Mini13,SK68XX_Mini12,SK68XX_Mini11,SK68XX_Mini10,SK68XX_Mini9,SK68XX_Mini39,SK68XX_Mini41,SK68XX_Mini40,SK68XX_Mini1,SK68XX_Mini38,SK68XX_Mini7,SK68XX_Mini42,SK68XX_Mini3,SK68XX_Mini6,SK68XX_Mini45,SK68XX_Mini44,SK68XX_Mini4,SK68XX_Mini5,SK68XX_Mini43,SK68XX_Mini2,SK68XX_Mini8,SK68XX_Mini27,SK68XX_Mini64 | SK68XXMini | C5184589
SN74AHCT1G125 | U2,U4 | SN74AHCT1G125 | C7484
D | D40,D6,D28,D58,D26,D51,D52,D8,D12,D42,D30,D29,D43,D21,D53,D31,D11,D47,D41,D45,D39,D35,D24,D44,D9,D5,D36,D61,D20,D3,D50,D38,D62,D27,D16,D18,D22,D54,D2,D46,D48,D57,D17,D37,D60,D59,D7,D23,D19,D55,D15,D32,D14,D25,D49,D33,D34,D1,D4,D10,D13,D56 | D_SOD-123_DO-35_Hybrid_DoubleSided_V2 | C2972760

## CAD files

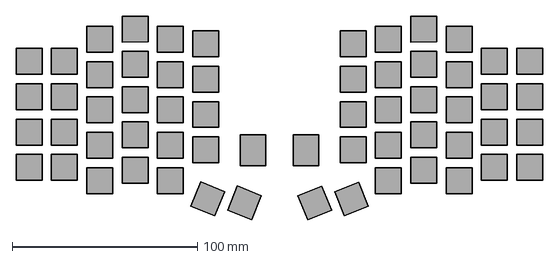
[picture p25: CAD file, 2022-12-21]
Case/Raw Files/Switch Cutouts - 2 Rotary.dxf
283.9 x 109.9 mm

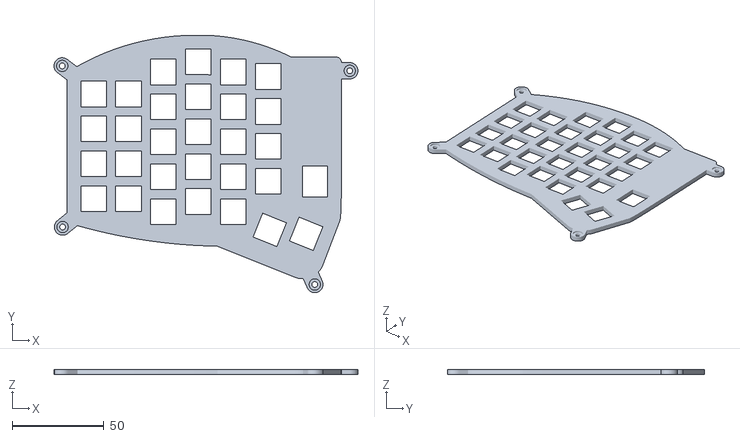
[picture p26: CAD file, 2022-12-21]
Case/Switch Plate - 2 Rotary Left.stl
165.9 x 140.5 x 3.00

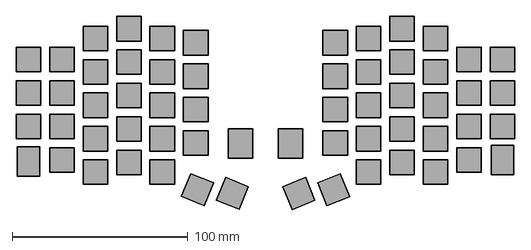
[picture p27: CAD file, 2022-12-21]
Case/Raw Files/Switch Cutouts - 4 Rotary.dxf
283.9 x 109.9 mm

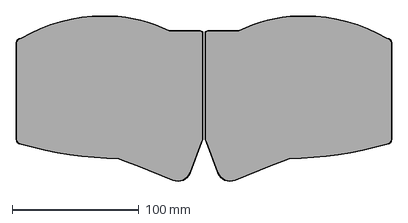
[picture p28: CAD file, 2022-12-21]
Case/Raw Files/Edge Cut.dxf
296.6 x 131.9 mm

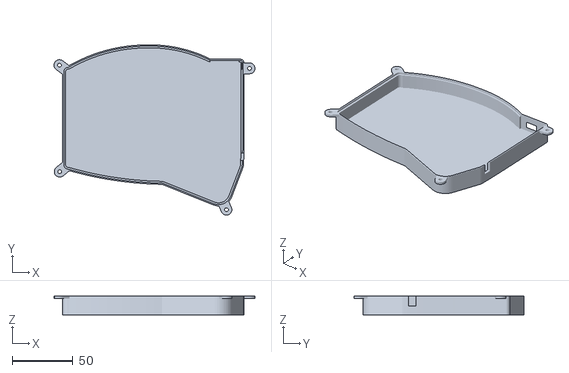
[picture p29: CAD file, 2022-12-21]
Case/Bottom Left.stl
165.9 x 140.5 x 15.5

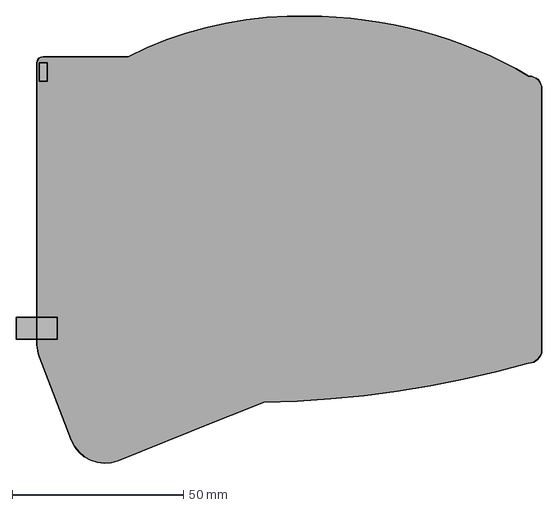
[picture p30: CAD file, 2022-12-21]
Case/Raw Files/Silk 2.dxf
153.5 x 131.9 mm

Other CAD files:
Case/Switch Plate - 4 Rotary Right.stl
Case/Switch Plate - 4 Rotary Left.stl
Case/Switch Plate - 2 Rotary Right.stl
Case/Bottom Right.stl
Case/Raw Files/Middle - Working.blend
Case/Raw Files/Middle FINAL Fused + Bottom.blend
Case/Raw Files/Middle FINAL Fused.blend
Case/Raw Files/Middle FINAL.blend
Case/Raw Files/Middle Fused.blend
Case/Raw Files/Middle.blend
Case/Raw Files/Plate.blend
Case/Raw Files/Switch Plate - 2 Rotary.blend
Case/Raw Files/Switch Plate - 4 Rotary.blend
Case/Raw Files/Top With Screw Holes.blend
Case/Raw Files/Top.blend

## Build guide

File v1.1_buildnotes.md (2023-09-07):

# Junco v1.1 Build notes
* Flipped all switch footprints to orient LED's away from user.
* Unified the LED orientation for easier builds.
* Flipped all LEDs to face toward board, allowing for automated assembly.
* Reworked all LED footprints to set the center X/Y point to 0,0, for automated assembly.
* Reworked all footprint sides (front/back) to better support automated assembly.
* Reworked LED footprints to use multiple through holes instead of edge cuts. This reduces manufacturing costs.
* Added combo diode footprints for SMD/through-hole.
* Improved diode orientation legibility.
* Rerouted all Pico traces to reduce the likeliness of shorts.
* Added GND/VCC planes for easier power routing.
* Flipped combo rotary encoders and switches, but maintained the encoder offset so that a plate update would not be needed. This required moving those LEDs to a lower position that intersects the switch center post hole. 
* Added a level shifter bypass. This was used to test the viability of SK6812 acting as a de-facto level shifter. That did not work, and the sk6812's increased draw caused the board to overheat. The bypass was left in the design regardless.
* Added hardware level handedness. Left hand GP18 is pulled high, right hand GP18 is pulled low. (I haven't submitted a QMK PR for this yet). @todo?
* Updated schematics to reflect handedness pin addition.

Wish list:
* The led drill holes are a little bigger than they need to be, so the LEDs tilt a bit during hand soldering. Tightening up the LED hole tolerances would make assembly easier.
* "Sandwich case" support. Adding holes to the PCB to allow standoff posts to go through it, so a pcb key plate and bottom plate can be used.

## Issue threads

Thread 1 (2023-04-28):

Switch rotation & QOL improvements

JellyTitan, 2023-04-28:
If nobody has started that yet, I'd like to give it a go.

There's some other QOL improvements i'd like to add:
* Through-hole/smd hybrid footprints. (I struggle with the SOD123 package, through holes are just my personal preference)
* Swap the MX hotswop footrprint for a combo MX/Choc v1/Choc V2 footprint. (Specifically, the ones found in [chunky 2040 rev2](https://github.com/freznel10/Chunky2040_rev2))
* Add GND VCC planes to simplify routing.
* Rotate the LEDs for a consistent orientation. (This complicates routing, but really helps with the build when your brain is on autopilot)
* On the thumb cluster, move the level shifter and underglow down a bit so they don't interfere with choc V2 MX keycaps.

Thoughts?

Daneski13, 2023-04-28:
I've been absolutely swamped with my classes this semester, so I'd really appreciate nocking stuff off the to-do list!

Very pro through-hole option for the diodes, I've gotten pretty good at soldering those little buggers at this point but man is it still a frustrating pain in the ass sometimes.

Rotating the switches is on the top of my [to-do](https://github.com/Daneski13/Junco/blob/main/CONTRIBUTING.md). It was a complete oversight that I didn't realize until I started soldering and somehow escaped the people who reviewed the PCB as well. Should be as easy as pressing "R" a couple times on each footprint (thumb keys might need some more finesse to ensure they stay in the same position if they were to be rotated as well), I just haven't had the time to re-route everything. If you were to undertake that feel free to route any way you see fit assuming the key and LED matrices stay the same.

Also, hardware level handedness would be a nice QOL improvement (pull an unused pin on the left side high and the corresponding pin on the right side low).

I'm sort of against using a combo Choc/MX footprint, non-goal in [philosophy](https://github.com/Daneski13/Junco#philosophy)) for the reason "MX switches should use MX spacing, Choc switches should use Choc spacing." Unless there's a lot more people than I'm aware of that actually using Choc switches with MX spacing? I've thought about creating a more "portable" variant that uses Choc spacing and either ditches the rotary encoders or uses smaller profile SMD encoders, just haven't had time to devise that yet.

On your last point I should note that pretty much all of the soldering is on the backside of the PCB (including the Picos unless you put the pico upside-down on the frontside), so nothing should interfere with keycaps, but feel free to move that level shifter around if you'd like to simplify routing or whatnot. On that note, since the SMD diodes are soldered on the backside it probably makes since for the through-hole diode option to allow for placement under the keycaps.

JellyTitan, 2023-04-29:
Sounds good! I've started.
There's some interesting techniques used here - like the LED footprint offset from zero.
I've put in the through-hole diodes. You mentioned all the soldering is done on the back. If the through hole diodes are used, then there will be components on the front and back. I'd like to propose soldering the through holes on the front, so that all components will be on the back. (I like to pull the solder mask on one side for those, so they can only be soldered in one way only - sort of a dirty poka-yoke)

Still working on the wiring and handedness pins.
I'll respect your MX/Choc spacing standard. (The choc v2 MX keys are hardly ever used - so i like to promote them when i can)

Daneski13, 2023-04-30:
Sounds good!

Yah the LED footprint offset just made it way easier to ensure they always had the right distance from the switch center.

JellyTitan, 2023-05-05:
I've got the basic rebuild done on branch key_rotation:
https://github.com/JellyTitan/Junco/tree/key_rotation

It still needs some code/doc/footprint cleanup work.

I'm putting together a pick and place config along with a BOM. I've never used PCB assembly before and want to try it out. I'm electrically 'not great'. (Electricity is magic and it scares me).
Any thoughts on which component would be best for the level shifter?
https://jlcpcb.com/parts/componentSearch?searchTxt=SN74AHCT1G125

Daneski13, 2023-05-06:
The VCC and GND planes make the routing way cleaner! Great work!

SN74AHCT1G125DBVR would be the proper choice I think, appears to be nearly identical to the SN74AHCT1G125DBVT model I recommend off of aliexpress. only difference from the datasheet looks like the wholesale minimum order quantity, so I would assume the DBVR has somewhat looser tolerances (which really isn't a concern for us).

I've never used PCB-parts assembly before either, since I've only done really small batches where a few hours soldering was a decent tradeoff to save money. Also, I wanted to use SK6803s over SK6812s so no need to force a lower the brightness for the LEDs.

Daneski13, 2023-05-06:
I should note that there are a lot of hole clearance violations relating to a bunch of your vias that board manufucturers will not like (I set the hole clearances to JLCPCB's parameters for vias, you can safely ignore hole clearance issues for non-vias)

JellyTitan, 2023-05-08:
Thanks for catching that!
I imported the JLCPCB config from this template repo:
https://github.com/sethhillbrand/kicad_templates

I then increased some stuff from the minimums and re-audited everything.
When you mention hole clearance issues - is it specifically the `copper to hole clearance`?
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

Daneski13, 2023-05-09:
No, clearance between tracks and vias is set manually with a custom rule. It's set at the proper 0.254mm, the “copper to hole width" rule has no effect on vias within the constraints tab:

```
(rule VIA_CLEAR_TO_TRACK
   (constraint clearance (min "0.254mm"))
   (condition "A.Type == 'Via' && B.Type == 'Track'"))
```

What I was referring to was hole to hole clearance which I had set at 0.5mm, which is the proper hole to hole clearance for Different nets on JLCPCB, considering its extremely unlikely you would have vias or holes part of the same net anywhere near each other on a decently designed keyboard PCB I went with 0.5. 0.254 is only the correct hole to hole clearance for vias of the  _same net_ which is why I had it set at 0.5.

I was also thinking of the DRC errors related to the holes on the LED footprint, for whatever reason I assumed those were vias and chalked it up to a clearance issue when in actuality it's an issue with the minimum drill hole size {“minimum through hole" constraint). For 1&2 layer PCBs the minimum drill hole size is 0.3mm for both through holes and vias, almost all the holes on your PCB are set to 0.25mm.

I should also note that the config your using is chopping the last decimal point on several constraints and that may cause issues . It seems that repo you pointed to is out of date as it hasn't been updated in 4 years and there's a few open issues that mention the values.

I'll just quickly detail all of issues with it that I see in that constraint screen shot you sent:
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
JellyTitan, 2023-06-03:
Quick update. The SK6802s finally came in, so i placed an order. It should be a few weeks now. Fingers crossed!

JellyTitan, 2023-06-03:
JLC is asking for another ~$30USD. I expected the "too many holes up charge", but the 'too many designs" charge was unexpected. Did you get that last order?

I'm going to try and cancel the order and rework with a revised LED footprint to see if I can't avoid the holes charge. Is there a particular footprint you had in mind? I haven't come across an LED footprint like that in the wild, but i do have some [Kailh scissor switch footprints](https://github.com/shikamiya/kicad-footprint-kailh-pg1425-x-switch/tree/master) that make square holes out of drills, so I have a solid reference to start from.

For the "too many designs" error, i think a manufacturing frame like the [Corne Cherry](https://github.com/foostan/crkbd/blob/main/corne-cherry/doc/v3/buildguide_en.md) might do the trick. (Really not sure though - this feels like another arbitrary fee).

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

daneski13, 2023-06-07:
Apologies for my slow response.

I did not have that fee, I just selected "2 designs" on the quote page and it wasn't a problem.

There was not a particular footprint i had in mind for the LEDs since I created the footprint myself originally, I was thinking to keep it simple with 5 drill holes. 1 larger one in the centre and 4 for the corners.

JellyTitan, 2023-06-07:
Thanks! I got the holes setup - i started before i saw your comment, so it's a 7 hole layout based on the pg1425. I'll revise if they throw it back with an extra fee. I'm working on the frame still. Hoping to get it back into production this week.

daneski13, 2023-06-08:
Awesom!

JellyTitan, 2023-08-10:
The new build works as expected. I'm updating the docs to submit a PR.
For versioning - would you like to go with V1.1 or V2.0? (I'm thinking 1.1 because the form factor is the same - but adding a handedness pin would suggest V2?)

daneski13, 2023-08-12:
Great to hear!! I agree that V1.1 would be appropriate if no updates to QMK is necessary.

azhizhinov, 2023-09-01:
Hello.
Thanks for your efforts.
Based on your both work, I've made my own design.
Universal PCB for both hands.
What do you think?
Do you want me to push my work into your repo?
Thanks in advance.
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

JellyTitan, 2023-09-04:
Looks great!
I'd like to keep my revision as the 1.1, because i think your double-sided board would be better suited to 2.0.
I'll try to finish the 1.1 docs tomorrow and then submit a PR.
I cloned a bunch of the footprints from the submodules and tweaked them a bit, so I'd like to put 1.1 in it's own subfolder.
[Sofle](https://github.com/josefadamcik/SofleKeyboard) has a pretty good structure for the variant breakouts in folders.

daneski13, 2023-09-04:
Appreciate the work @azhizhinov! Originally I was against doing a double sided board since it can make the soldering job somewhat more error-prone. However, if that's what people are leaning towards for simplicity in the ordering process I'm not necessarily opposed.

Is it cheaper to go with a single PCB or to stick with a panelized board?  Also, with this single board design how would one go about placing the controller onto the board given that there is not 2 different through-holes for the Pico depending on left/right? Wouldn't one side be forced to have the Pico on the opposite side of the board or upside-down to match the connections?

azhizhinov, 2023-09-04:
Hello.
It might be differences between countries, but - yes, single PCB is cheaper comparing to a panellized twins in most cases.
2 designs per board are more expensive from the start.
Yes, single PCB can be challenging, I'm not pushing this design hard.
And now I'm thinking pushing this design in to your repo is not a good idea, cos you'll be receiving odd responsibility for my possible errors. :-)
Yes, the Pico placement can be inconvenient for someone, but if the keyboard will be wearing a case, when it will be no problem, from my point of view.
But I can provide you with sources, if you want, and you can review them and make a decision, or make some improvements. :-)

JellyTitan, 2023-09-05:
@daneski13
V1.1 is well developed enough that I'll be submitting a PR. I'd like to close this thread, as it seems to have gone a bit off topic.

Closed 2023-09-05.

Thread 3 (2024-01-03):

Can the diode between VBUS & VSYS be removed?

JellyTitan, 2024-01-03:
I used the Junco circuit to build a Sofle variant. When reviewing with a thermal imager, i noticed the hottest bit of the board was the diode between the VBUS and VSYS pins.  I suspect the Junco has a similar issue, but I've not validated.
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

According to the [Pico docs](https://datasheets.raspberrypi.com/pico/pico-datasheet.pdf), there is an internal diode between VBUS & VSYS already?
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

Was that diode added to the Junco to support a specific Pico clone that does not have the diode between vbus & vsys? If not, have you tried removing it?

daneski13, 2024-01-07:
Apologies for the late response, been very busy the last several months finishing up my last year at University. Junco was designed to be agnostic about which side of the board is plugged in and I don't entirely remember what the reasoning was for that diode just that it had something to do ensuring no issues in the event a pico clone didn't already diode it. If only one side of a split is meant to be plugged in you could easily omit it.

92F isn't a concerning temperature and is lower than body temperature. As far as I know, most diodes are designed to operate with recommended bounds of around 212F but I've heard some have absolute limits of 175C (upwards of 300F) with specific upper limits dependent on the model. Since a USB is only pushing 5V through that thing I wouldn't be concerned about temps at all.

Honored I contributed to another design.

Also, I noticed you linked to a key-swap issue which reminded me of an oversight in my original wiring for the right side's thumb keys that was fixed by swapping the keys in QMK's firmware. I haven't had a chance to finish building your revision, so do you know if the right side's thumb keys were acting "odd" with your revision? Looking at your revision of Junco I believe it fixed my mistake and I haven't pushed swapping it back in QMK for the new revision.

daneski13, 2024-01-07:
On that note re the key swap, if you based Sofle-Pico's firmware on Junco's that would've been my fault 🤦

JellyTitan, 2024-01-08:
No worries! Your design is sound! (Congrats on finishing up uni BTW).
I think I got things figured on that particular diode.
It looks like the official version of the Picos _do_ have a diode between vbus and vsys -but some clones do not!
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

When using clones, the power for both boards is all flowing through that single diode. Based on [this video](https://www.youtube.com/watch?v=3PH9jzRsb5E), it looks like using a 1N5817 Shottky diode there might be a better choice, as opposed to an in4148.

Thoughts?

(Thanks for looking at the keyswap keyswap issue - turns out it was an easy config fix!)

daneski13, 2024-01-08:
Thanks! Not quite out of the woods yet, in the last semester.

Yes, a Schottky diode would be the proper choice, but then it makes for yet another part to source. The voltage drop from a 4148 isn't significant enough to really cause any issues, especially since the other Pico runs at 3.3V anyway. I remember my brother noticed a slight dimming of the "slave" side's LEDs on his build when every single LED was set to white at maximum brightness (i.e. worst-case scenario for LED voltage draw) but I don't remember if re-soldering the diode for a better connection or decreasing the brightness by a smidge from max did the trick. Possibly could be a noticeable issue if someone used big boy 12ma SK6812MINI-E rather than the recommended 3ma SK6803MINI-E.

The thumb-key mistake I was referring to was this bugger on my original wiring (at least I think that was the problem if such a problem ever existed in the first place):

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

I did this to the QMK config to make it work properly, you can see it goes 34210 instead of 43210 like the left side's:

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

JellyTitan, 2024-01-10:
Thanks! Getting the VIA config working made me go over everything with a fine tooth comb.
I ran some experiments, and it looks like changing that diode can make it run up to 30 degrees cooler.
I totally get the design choice to simplify the BOM by omitting an extra diode though.
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

JellyTitan, 2024-01-15:
I had the Junco case off today, so I took a pic. Nothing actionable, just sharing because it's interesting.
It looks like it's hitting 140F on the diode.
I saw high around 130F on the MCU.
Do with this information what you will.
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

Closed 2024-03-11.

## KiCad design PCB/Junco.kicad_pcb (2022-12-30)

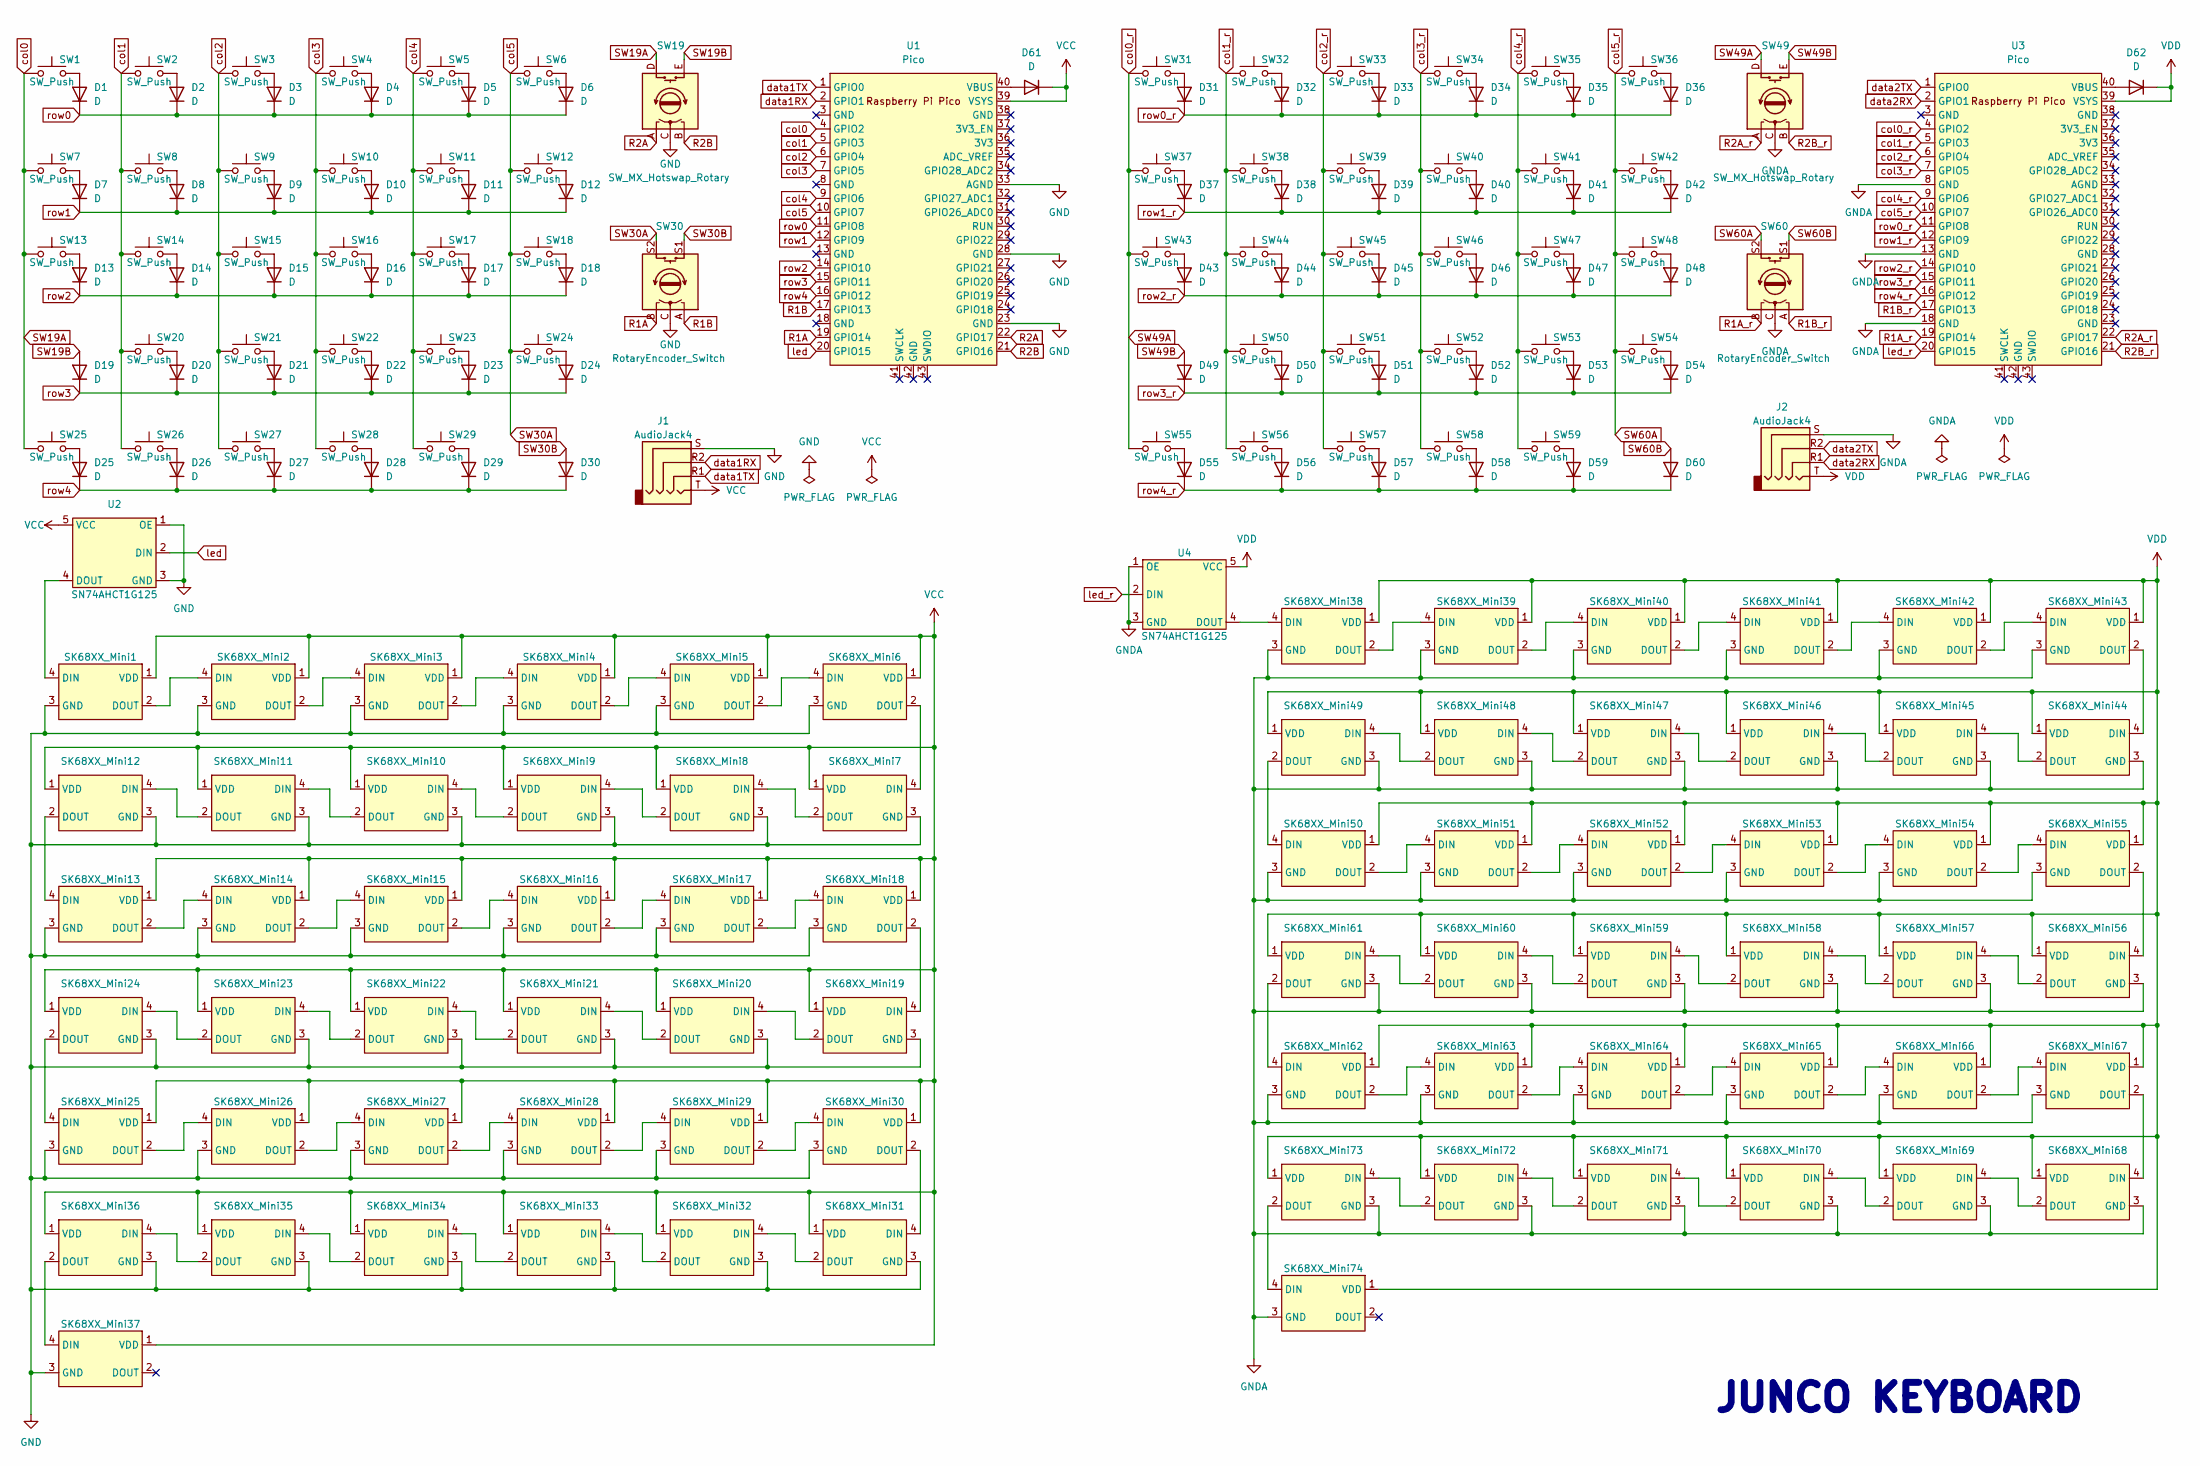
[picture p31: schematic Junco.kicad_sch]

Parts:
D1, D2, D3, D4, D5, D6, D7, D8, D9, D10, D11, D12, D13, D14, D15, D16, D17, D18, D19, D20, D21, D22, D23, D24, D25, D26, D27, D28, D29, D30, D31, D32, D33, D34, D35, D36, D37, D38, D39, D40, D41, D42, D43, D44, D45, D46, D47, D48, D49, D50, D51, D52, D53, D54, D55, D56, D57, D58, D59, D60, D61, D62: D; D_SOD-123
J1, J2: AudioJack4; TRRS_PJ320A
SK68XX_Mini1, SK68XX_Mini2, SK68XX_Mini3, SK68XX_Mini4, SK68XX_Mini5, SK68XX_Mini6, SK68XX_Mini7, SK68XX_Mini8, SK68XX_Mini38, SK68XX_Mini39, SK68XX_Mini40, SK68XX_Mini41, SK68XX_Mini42, SK68XX_Mini43, SK68XX_Mini44, SK68XX_Mini45: SK68XXMini
SK68XX_Mini9, SK68XX_Mini10, SK68XX_Mini11, SK68XX_Mini12, SK68XX_Mini13, SK68XX_Mini14, SK68XX_Mini21, SK68XX_Mini22, SK68XX_Mini23, SK68XX_Mini24, SK68XX_Mini25, SK68XX_Mini26, SK68XX_Mini35, SK68XX_Mini36, SK68XX_Mini37, SK68XX_Mini52, SK68XX_Mini53, SK68XX_Mini54, SK68XX_Mini55, SK68XX_Mini56, SK68XX_Mini57, SK68XX_Mini64, SK68XX_Mini65, SK68XX_Mini66, SK68XX_Mini67, SK68XX_Mini68, SK68XX_Mini69, SK68XX_Mini70, SK68XX_Mini71: SK68XXMini; SK68XXMini_Offset_Flipped
SK68XX_Mini15, SK68XX_Mini16, SK68XX_Mini17, SK68XX_Mini18, SK68XX_Mini19, SK68XX_Mini20, SK68XX_Mini27, SK68XX_Mini28, SK68XX_Mini29, SK68XX_Mini30, SK68XX_Mini31, SK68XX_Mini32, SK68XX_Mini33, SK68XX_Mini34, SK68XX_Mini46, SK68XX_Mini47, SK68XX_Mini48, SK68XX_Mini49, SK68XX_Mini50, SK68XX_Mini51, SK68XX_Mini58, SK68XX_Mini59, SK68XX_Mini60, SK68XX_Mini61, SK68XX_Mini62, SK68XX_Mini63, SK68XX_Mini72, SK68XX_Mini73, SK68XX_Mini74: SK68XXMini; SK68XXMini_Offset
SW1, SW2, SW3, SW4, SW5, SW6, SW7, SW8, SW9, SW10, SW11, SW12, SW13, SW14, SW15, SW16, SW17, SW18, SW20, SW21, SW22, SW23, SW24, SW25, SW26, SW27, SW31, SW32, SW33, SW34, SW35, SW36, SW37, SW38, SW39, SW40, SW41, SW42, SW43, SW44, SW45, SW46, SW47, SW48, SW50, SW51, SW52, SW53, SW54, SW55, SW56, SW57: SW_Push; SW_MX_HS_1u
SW19, SW49: SW_MX_Hotswap_Rotary
SW28, SW29, SW58, SW59: SW_Push; SW_MX_HS_1.5u
SW30, SW60: RotaryEncoder_Switch; EC11_Rotary_Encoder
U1, U3: Pico; RPi_Pico_SMD_TH
U2, U4: SN74AHCT1G125

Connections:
GND: J1.S, SK68XX_Mini1.3 (GND), SK68XX_Mini2.3 (GND), SK68XX_Mini3.3 (GND), SK68XX_Mini4.3 (GND), SK68XX_Mini5.3 (GND), SK68XX_Mini6.3 (GND), SK68XX_Mini7.3 (GND), SK68XX_Mini8.3 (GND), SK68XX_Mini9.3 (GND), SK68XX_Mini10.3 (GND), SK68XX_Mini11.3 (GND), SK68XX_Mini12.3 (GND), SK68XX_Mini13.3 (GND), SK68XX_Mini14.3 (GND), SK68XX_Mini15.3 (GND), SK68XX_Mini16.3 (GND), SK68XX_Mini17.3 (GND), SK68XX_Mini18.3 (GND), SK68XX_Mini19.3 (GND), SK68XX_Mini20.3 (GND), SK68XX_Mini21.3 (GND), SK68XX_Mini22.3 (GND), SK68XX_Mini23.3 (GND), SK68XX_Mini24.3 (GND), SK68XX_Mini25.3 (GND), SK68XX_Mini26.3 (GND), SK68XX_Mini27.3 (GND), SK68XX_Mini28.3 (GND), SK68XX_Mini29.3 (GND), SK68XX_Mini30.3 (GND), SK68XX_Mini31.3 (GND), SK68XX_Mini32.3 (GND), SK68XX_Mini33.3 (GND), SK68XX_Mini34.3 (GND), SK68XX_Mini35.3 (GND), SK68XX_Mini36.3 (GND), SK68XX_Mini37.3 (GND), SW19.C, SW30.C, U1.23 (GND), U1.28 (GND), U1.33 (AGND), U2.1 (OE), U2.3 (GND)
GNDA: J2.S, SK68XX_Mini38.3 (GND), SK68XX_Mini39.3 (GND), SK68XX_Mini40.3 (GND), SK68XX_Mini41.3 (GND), SK68XX_Mini42.3 (GND), SK68XX_Mini43.3 (GND), SK68XX_Mini44.3 (GND), SK68XX_Mini45.3 (GND), SK68XX_Mini46.3 (GND), SK68XX_Mini47.3 (GND), SK68XX_Mini48.3 (GND), SK68XX_Mini49.3 (GND), SK68XX_Mini50.3 (GND), SK68XX_Mini51.3 (GND), SK68XX_Mini52.3 (GND), SK68XX_Mini53.3 (GND), SK68XX_Mini54.3 (GND), SK68XX_Mini55.3 (GND), SK68XX_Mini56.3 (GND), SK68XX_Mini57.3 (GND), SK68XX_Mini58.3 (GND), SK68XX_Mini59.3 (GND), SK68XX_Mini60.3 (GND), SK68XX_Mini61.3 (GND), SK68XX_Mini62.3 (GND), SK68XX_Mini63.3 (GND), SK68XX_Mini64.3 (GND), SK68XX_Mini65.3 (GND), SK68XX_Mini66.3 (GND), SK68XX_Mini67.3 (GND), SK68XX_Mini68.3 (GND), SK68XX_Mini69.3 (GND), SK68XX_Mini70.3 (GND), SK68XX_Mini71.3 (GND), SK68XX_Mini72.3 (GND), SK68XX_Mini73.3 (GND), SK68XX_Mini74.3 (GND), SW49.C, SW60.C, U3.8 (GND), U3.13 (GND), U3.18 (GND), U4.1 (OE), U4.3 (GND)
unnamed: D1.2 (A), SW1.2
unnamed: D2.2 (A), SW2.2
unnamed: D3.2 (A), SW3.2
unnamed: D4.2 (A), SW4.2
unnamed: D5.2 (A), SW5.2
unnamed: D6.2 (A), SW6.2
unnamed: D7.2 (A), SW7.2
unnamed: D8.2 (A), SW8.2
unnamed: D9.2 (A), SW9.2
unnamed: D10.2 (A), SW10.2
unnamed: D11.2 (A), SW11.2
unnamed: D12.2 (A), SW12.2
unnamed: D13.2 (A), SW13.2
unnamed: D14.2 (A), SW14.2
unnamed: D15.2 (A), SW15.2
unnamed: D16.2 (A), SW16.2
unnamed: D17.2 (A), SW17.2
unnamed: D18.2 (A), SW18.2
unnamed: D20.2 (A), SW20.2
unnamed: D21.2 (A), SW21.2
unnamed: D22.2 (A), SW22.2
unnamed: D23.2 (A), SW23.2
unnamed: D24.2 (A), SW24.2
unnamed: D25.2 (A), SW25.2
unnamed: D26.2 (A), SW26.2
unnamed: D27.2 (A), SW27.2
unnamed: D28.2 (A), SW28.2
unnamed: D29.2 (A), SW29.2
unnamed: D31.2 (A), SW31.2
unnamed: D32.2 (A), SW32.2
unnamed: D33.2 (A), SW33.2
unnamed: D34.2 (A), SW34.2
unnamed: D35.2 (A), SW35.2
unnamed: D36.2 (A), SW36.2
unnamed: D37.2 (A), SW37.2
unnamed: D38.2 (A), SW38.2
unnamed: D39.2 (A), SW39.2
unnamed: D40.2 (A), SW40.2
unnamed: D41.2 (A), SW41.2
unnamed: D42.2 (A), SW42.2
unnamed: D43.2 (A), SW43.2
unnamed: D44.2 (A), SW44.2
unnamed: D45.2 (A), SW45.2
unnamed: D46.2 (A), SW46.2
unnamed: D47.2 (A), SW47.2
unnamed: D48.2 (A), SW48.2
unnamed: D50.2 (A), SW50.2
unnamed: D51.2 (A), SW51.2
unnamed: D52.2 (A), SW52.2
unnamed: D53.2 (A), SW53.2
unnamed: D54.2 (A), SW54.2
unnamed: D55.2 (A), SW55.2
unnamed: D56.2 (A), SW56.2
unnamed: D57.2 (A), SW57.2
unnamed: D58.2 (A), SW58.2
unnamed: D59.2 (A), SW59.2
unnamed: D61.2 (A), U1.40 (VBUS)
unnamed: D62.2 (A), U3.40 (VBUS)
unnamed: SK68XX_Mini1.2 (DOUT), SK68XX_Mini2.4 (DIN)
unnamed: SK68XX_Mini1.4 (DIN), U2.4 (DOUT)
unnamed: SK68XX_Mini2.2 (DOUT), SK68XX_Mini3.4 (DIN)
unnamed: SK68XX_Mini3.2 (DOUT), SK68XX_Mini4.4 (DIN)
unnamed: SK68XX_Mini4.2 (DOUT), SK68XX_Mini5.4 (DIN)
unnamed: SK68XX_Mini5.2 (DOUT), SK68XX_Mini6.4 (DIN)
unnamed: SK68XX_Mini6.2 (DOUT), SK68XX_Mini7.4 (DIN)
unnamed: SK68XX_Mini7.2 (DOUT), SK68XX_Mini8.4 (DIN)
unnamed: SK68XX_Mini8.2 (DOUT), SK68XX_Mini9.4 (DIN)
unnamed: SK68XX_Mini10.2 (DOUT), SK68XX_Mini11.4 (DIN)
unnamed: SK68XX_Mini9.2 (DOUT), SK68XX_Mini10.4 (DIN)
unnamed: SK68XX_Mini11.2 (DOUT), SK68XX_Mini12.4 (DIN)
unnamed: SK68XX_Mini12.2 (DOUT), SK68XX_Mini13.4 (DIN)
unnamed: SK68XX_Mini13.2 (DOUT), SK68XX_Mini14.4 (DIN)
unnamed: SK68XX_Mini14.2 (DOUT), SK68XX_Mini15.4 (DIN)
unnamed: SK68XX_Mini15.2 (DOUT), SK68XX_Mini16.4 (DIN)
unnamed: SK68XX_Mini16.2 (DOUT), SK68XX_Mini17.4 (DIN)
unnamed: SK68XX_Mini17.2 (DOUT), SK68XX_Mini18.4 (DIN)
unnamed: SK68XX_Mini18.2 (DOUT), SK68XX_Mini19.4 (DIN)
unnamed: SK68XX_Mini19.2 (DOUT), SK68XX_Mini20.4 (DIN)
unnamed: SK68XX_Mini20.2 (DOUT), SK68XX_Mini21.4 (DIN)
unnamed: SK68XX_Mini21.2 (DOUT), SK68XX_Mini22.4 (DIN)
unnamed: SK68XX_Mini22.2 (DOUT), SK68XX_Mini23.4 (DIN)
unnamed: SK68XX_Mini23.2 (DOUT), SK68XX_Mini24.4 (DIN)
unnamed: SK68XX_Mini24.2 (DOUT), SK68XX_Mini25.4 (DIN)
unnamed: SK68XX_Mini25.2 (DOUT), SK68XX_Mini26.4 (DIN)
unnamed: SK68XX_Mini26.2 (DOUT), SK68XX_Mini27.4 (DIN)
unnamed: SK68XX_Mini27.2 (DOUT), SK68XX_Mini28.4 (DIN)
unnamed: SK68XX_Mini28.2 (DOUT), SK68XX_Mini29.4 (DIN)
unnamed: SK68XX_Mini29.2 (DOUT), SK68XX_Mini30.4 (DIN)
unnamed: SK68XX_Mini30.2 (DOUT), SK68XX_Mini31.4 (DIN)
unnamed: SK68XX_Mini31.2 (DOUT), SK68XX_Mini32.4 (DIN)
unnamed: SK68XX_Mini32.2 (DOUT), SK68XX_Mini33.4 (DIN)
unnamed: SK68XX_Mini33.2 (DOUT), SK68XX_Mini34.4 (DIN)
unnamed: SK68XX_Mini34.2 (DOUT), SK68XX_Mini35.4 (DIN)
unnamed: SK68XX_Mini35.2 (DOUT), SK68XX_Mini36.4 (DIN)
unnamed: SK68XX_Mini36.2 (DOUT), SK68XX_Mini37.4 (DIN)
unnamed: SK68XX_Mini38.2 (DOUT), SK68XX_Mini39.4 (DIN)
unnamed: SK68XX_Mini38.4 (DIN), U4.4 (DOUT)
unnamed: SK68XX_Mini39.2 (DOUT), SK68XX_Mini40.4 (DIN)
unnamed: SK68XX_Mini40.2 (DOUT), SK68XX_Mini41.4 (DIN)
unnamed: SK68XX_Mini41.2 (DOUT), SK68XX_Mini42.4 (DIN)
unnamed: SK68XX_Mini42.2 (DOUT), SK68XX_Mini43.4 (DIN)
unnamed: SK68XX_Mini43.2 (DOUT), SK68XX_Mini44.4 (DIN)
unnamed: SK68XX_Mini44.2 (DOUT), SK68XX_Mini45.4 (DIN)
unnamed: SK68XX_Mini45.2 (DOUT), SK68XX_Mini46.4 (DIN)
unnamed: SK68XX_Mini46.2 (DOUT), SK68XX_Mini47.4 (DIN)
unnamed: SK68XX_Mini47.2 (DOUT), SK68XX_Mini48.4 (DIN)
unnamed: SK68XX_Mini48.2 (DOUT), SK68XX_Mini49.4 (DIN)
unnamed: SK68XX_Mini49.2 (DOUT), SK68XX_Mini50.4 (DIN)
unnamed: SK68XX_Mini50.2 (DOUT), SK68XX_Mini51.4 (DIN)
unnamed: SK68XX_Mini51.2 (DOUT), SK68XX_Mini52.4 (DIN)
unnamed: SK68XX_Mini52.2 (DOUT), SK68XX_Mini53.4 (DIN)
unnamed: SK68XX_Mini53.2 (DOUT), SK68XX_Mini54.4 (DIN)
unnamed: SK68XX_Mini54.2 (DOUT), SK68XX_Mini55.4 (DIN)
unnamed: SK68XX_Mini55.2 (DOUT), SK68XX_Mini56.4 (DIN)
unnamed: SK68XX_Mini56.2 (DOUT), SK68XX_Mini57.4 (DIN)
unnamed: SK68XX_Mini57.2 (DOUT), SK68XX_Mini58.4 (DIN)
unnamed: SK68XX_Mini58.2 (DOUT), SK68XX_Mini59.4 (DIN)
unnamed: SK68XX_Mini59.2 (DOUT), SK68XX_Mini60.4 (DIN)
unnamed: SK68XX_Mini60.2 (DOUT), SK68XX_Mini61.4 (DIN)
unnamed: SK68XX_Mini61.2 (DOUT), SK68XX_Mini62.4 (DIN)
unnamed: SK68XX_Mini62.2 (DOUT), SK68XX_Mini63.4 (DIN)
unnamed: SK68XX_Mini63.2 (DOUT), SK68XX_Mini64.4 (DIN)
unnamed: SK68XX_Mini64.2 (DOUT), SK68XX_Mini65.4 (DIN)
unnamed: SK68XX_Mini65.2 (DOUT), SK68XX_Mini66.4 (DIN)
unnamed: SK68XX_Mini66.2 (DOUT), SK68XX_Mini67.4 (DIN)
unnamed: SK68XX_Mini67.2 (DOUT), SK68XX_Mini68.4 (DIN)
unnamed: SK68XX_Mini68.2 (DOUT), SK68XX_Mini69.4 (DIN)
unnamed: SK68XX_Mini69.2 (DOUT), SK68XX_Mini70.4 (DIN)
unnamed: SK68XX_Mini70.2 (DOUT), SK68XX_Mini71.4 (DIN)
unnamed: SK68XX_Mini71.2 (DOUT), SK68XX_Mini72.4 (DIN)
unnamed: SK68XX_Mini72.2 (DOUT), SK68XX_Mini73.4 (DIN)
unnamed: SK68XX_Mini73.2 (DOUT), SK68XX_Mini74.4 (DIN)
R1A: SW30.B, U1.19 (GPIO14)
R1A_r: SW60.B, U3.19 (GPIO14)
R1B: SW30.A, U1.17 (GPIO13)
R1B_r: SW60.A, U3.17 (GPIO13)
R2A: SW19.A, U1.22 (GPIO17)
R2A_r: SW49.A, U3.22 (GPIO17)
R2B: SW19.B, U1.21 (GPIO16)
R2B_r: SW49.B, U3.21 (GPIO16)
SW19A: SW1.1, SW7.1, SW13.1, SW19.1 (SW), SW19.D (S1), SW25.1, U1.4 (GPIO2)
SW19B: D19.2 (A), SW19.2 (SW), SW19.E (S2)
SW30A: SW6.1, SW12.1, SW18.1, SW24.1, SW30.S2, U1.10 (GPIO7)
SW30B: D30.2 (A), SW30.S1
SW49A: SW31.1, SW37.1, SW43.1, SW49.1 (SW), SW49.D (S1), SW55.1, U3.4 (GPIO2)
SW49B: D49.2 (A), SW49.2 (SW), SW49.E (S2)
SW60A: SW36.1, SW42.1, SW48.1, SW54.1, SW60.S2, U3.10 (GPIO7)
SW60B: D60.2 (A), SW60.S1
VCC: D61.1 (K), J1.T, SK68XX_Mini1.1 (VDD), SK68XX_Mini2.1 (VDD), SK68XX_Mini3.1 (VDD), SK68XX_Mini4.1 (VDD), SK68XX_Mini5.1 (VDD), SK68XX_Mini6.1 (VDD), SK68XX_Mini7.1 (VDD), SK68XX_Mini8.1 (VDD), SK68XX_Mini9.1 (VDD), SK68XX_Mini10.1 (VDD), SK68XX_Mini11.1 (VDD), SK68XX_Mini12.1 (VDD), SK68XX_Mini13.1 (VDD), SK68XX_Mini14.1 (VDD), SK68XX_Mini15.1 (VDD), SK68XX_Mini16.1 (VDD), SK68XX_Mini17.1 (VDD), SK68XX_Mini18.1 (VDD), SK68XX_Mini19.1 (VDD), SK68XX_Mini20.1 (VDD), SK68XX_Mini21.1 (VDD), SK68XX_Mini22.1 (VDD), SK68XX_Mini23.1 (VDD), SK68XX_Mini24.1 (VDD), SK68XX_Mini25.1 (VDD), SK68XX_Mini26.1 (VDD), SK68XX_Mini27.1 (VDD), SK68XX_Mini28.1 (VDD), SK68XX_Mini29.1 (VDD), SK68XX_Mini30.1 (VDD), SK68XX_Mini31.1 (VDD), SK68XX_Mini32.1 (VDD), SK68XX_Mini33.1 (VDD), SK68XX_Mini34.1 (VDD), SK68XX_Mini35.1 (VDD), SK68XX_Mini36.1 (VDD), SK68XX_Mini37.1 (VDD), U1.39 (VSYS), U2.5 (VCC)
VDD: D62.1 (K), J2.T, SK68XX_Mini38.1 (VDD), SK68XX_Mini39.1 (VDD), SK68XX_Mini40.1 (VDD), SK68XX_Mini41.1 (VDD), SK68XX_Mini42.1 (VDD), SK68XX_Mini43.1 (VDD), SK68XX_Mini44.1 (VDD), SK68XX_Mini45.1 (VDD), SK68XX_Mini46.1 (VDD), SK68XX_Mini47.1 (VDD), SK68XX_Mini48.1 (VDD), SK68XX_Mini49.1 (VDD), SK68XX_Mini50.1 (VDD), SK68XX_Mini51.1 (VDD), SK68XX_Mini52.1 (VDD), SK68XX_Mini53.1 (VDD), SK68XX_Mini54.1 (VDD), SK68XX_Mini55.1 (VDD), SK68XX_Mini56.1 (VDD), SK68XX_Mini57.1 (VDD), SK68XX_Mini58.1 (VDD), SK68XX_Mini59.1 (VDD), SK68XX_Mini60.1 (VDD), SK68XX_Mini61.1 (VDD), SK68XX_Mini62.1 (VDD), SK68XX_Mini63.1 (VDD), SK68XX_Mini64.1 (VDD), SK68XX_Mini65.1 (VDD), SK68XX_Mini66.1 (VDD), SK68XX_Mini67.1 (VDD), SK68XX_Mini68.1 (VDD), SK68XX_Mini69.1 (VDD), SK68XX_Mini70.1 (VDD), SK68XX_Mini71.1 (VDD), SK68XX_Mini72.1 (VDD), SK68XX_Mini73.1 (VDD), SK68XX_Mini74.1 (VDD), U3.39 (VSYS), U4.5 (VCC)
col1: SW2.1, SW8.1, SW14.1, SW20.1, SW26.1, U1.5 (GPIO3)
col1_r: SW32.1, SW38.1, SW44.1, SW50.1, SW56.1, U3.5 (GPIO3)
col2: SW3.1, SW9.1, SW15.1, SW21.1, SW27.1, U1.6 (GPIO4)
col2_r: SW33.1, SW39.1, SW45.1, SW51.1, SW57.1, U3.6 (GPIO4)
col3: SW4.1, SW10.1, SW16.1, SW22.1, SW28.1, U1.7 (GPIO5)
col3_r: SW34.1, SW40.1, SW46.1, SW52.1, SW58.1, U3.7 (GPIO5)
col4: SW5.1, SW11.1, SW17.1, SW23.1, SW29.1, U1.9 (GPIO6)
col4_r: SW35.1, SW41.1, SW47.1, SW53.1, SW59.1, U3.9 (GPIO6)
data1RX: J1.R2, U1.2 (GPIO1)
data1TX: J1.R1, U1.1 (GPIO0)
data2RX: J2.R1, U3.2 (GPIO1)
data2TX: J2.R2, U3.1 (GPIO0)
led: U1.20 (GPIO15), U2.2 (DIN)
led_r: U3.20 (GPIO15), U4.2 (DIN)
row0: D1.1 (K), D2.1 (K), D3.1 (K), D4.1 (K), D5.1 (K), D6.1 (K), U1.11 (GPIO8)
row0_r: D31.1 (K), D32.1 (K), D33.1 (K), D34.1 (K), D35.1 (K), D36.1 (K), U3.11 (GPIO8)
row1: D7.1 (K), D8.1 (K), D9.1 (K), D10.1 (K), D11.1 (K), D12.1 (K), U1.12 (GPIO9)
row1_r: D37.1 (K), D38.1 (K), D39.1 (K), D40.1 (K), D41.1 (K), D42.1 (K), U3.12 (GPIO9)
row2: D13.1 (K), D14.1 (K), D15.1 (K), D16.1 (K), D17.1 (K), D18.1 (K), U1.14 (GPIO10)
row2_r: D43.1 (K), D44.1 (K), D45.1 (K), D46.1 (K), D47.1 (K), D48.1 (K), U3.14 (GPIO10)
row3: D19.1 (K), D20.1 (K), D21.1 (K), D22.1 (K), D23.1 (K), D24.1 (K), U1.15 (GPIO11)
row3_r: D49.1 (K), D50.1 (K), D51.1 (K), D52.1 (K), D53.1 (K), D54.1 (K), U3.15 (GPIO11)
row4: D25.1 (K), D26.1 (K), D27.1 (K), D28.1 (K), D29.1 (K), D30.1 (K), U1.16 (GPIO12)
row4_r: D55.1 (K), D56.1 (K), D57.1 (K), D58.1 (K), D59.1 (K), D60.1 (K), U3.16 (GPIO12)

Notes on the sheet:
JUNCO KEYBOARD

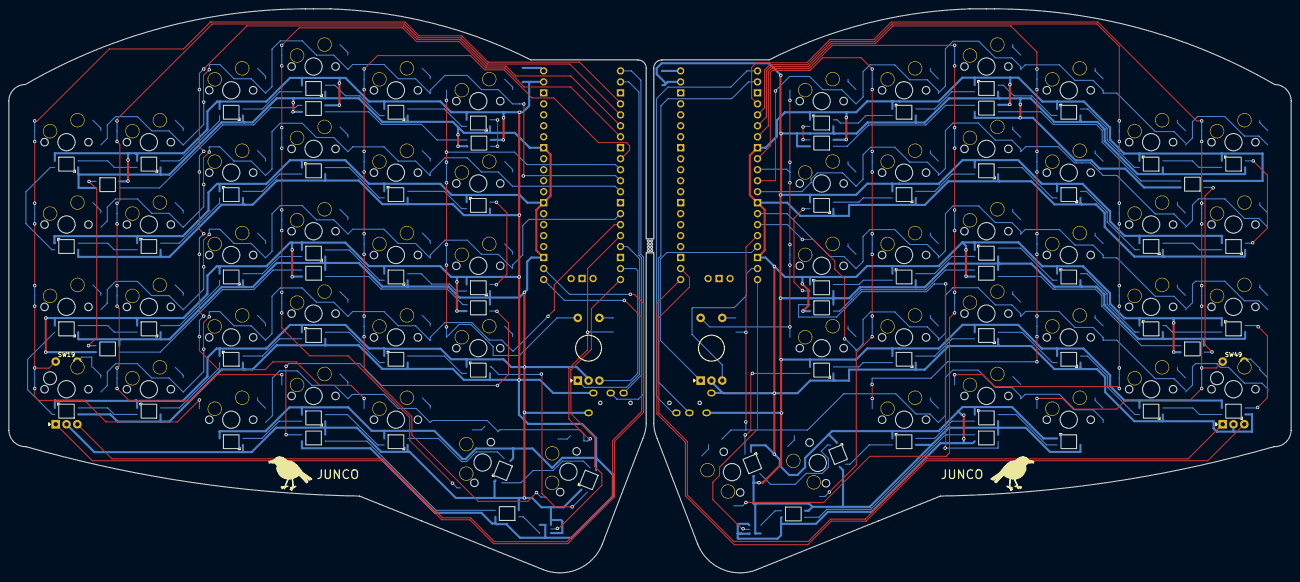
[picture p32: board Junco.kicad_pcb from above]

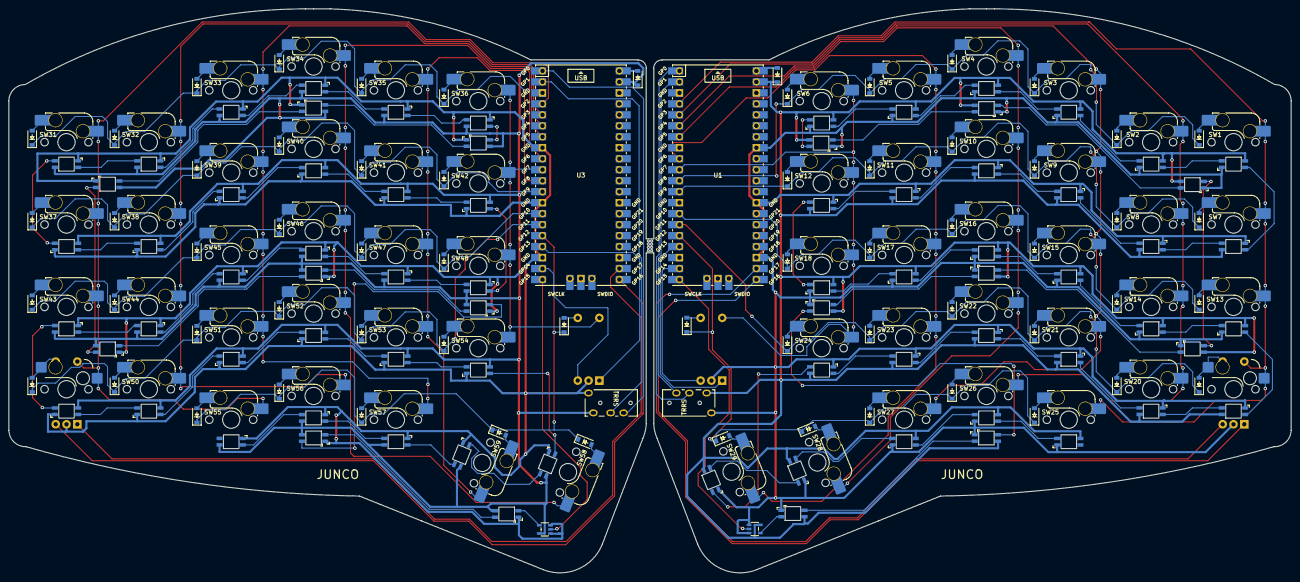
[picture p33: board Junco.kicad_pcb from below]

Board: 2 copper layers, 296.6 x 130.5 mm, 203 parts (62 on the bottom side), 176 nets.

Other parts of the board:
Ref**: Val**; Junco

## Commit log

2022-12-21 remove submodule folders
    [CON_MJ-4PP-9.step, CON_SM02B-SRSS-TB.step, CON_SM04B-SRSS-TB.step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]
2022-12-30 Clean up some traces
    [Junco.kicad_pcb, Junco.kicad_sch]
2023-09-07 Key rotation & other QOL improvements (#2)
    * Keycap rotation
    Swapped in smd/through-hole diode footprints
    * comitt before pcb led rotation unification
    already updated LED orientation on schematic
    * Finished main led flip
    underglow flip remains
    * Added hardware 'handedness on gp18 with default LH
    * Updated corner encoders
    Created flipped encoder/switch combo footprint
    Created short offset LED for encoder/switch combo
    Encoder routing
    Added build notes
    * Wiring cleanup
    * Routing cleanup
    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
    [JUNCO v1.1 BOM JLC.csv, JUNCO v1.1 PNP Backside JLC.csv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]

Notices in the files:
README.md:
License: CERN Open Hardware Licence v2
